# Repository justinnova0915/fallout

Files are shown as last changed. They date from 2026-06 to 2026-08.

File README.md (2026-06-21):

# TALOS-01 // Desktop Helper

The TALOS-01 is a desktop device designed to make navigating workspace-heavy, tiling operating systems (like Arch Linux Hyprland or macOS) more straightforward by making it physical. No more memorizing convoluted keyboard shortcuts just to move a window. This is my Fallout project for Hack Club, so I'm super excited to share it!

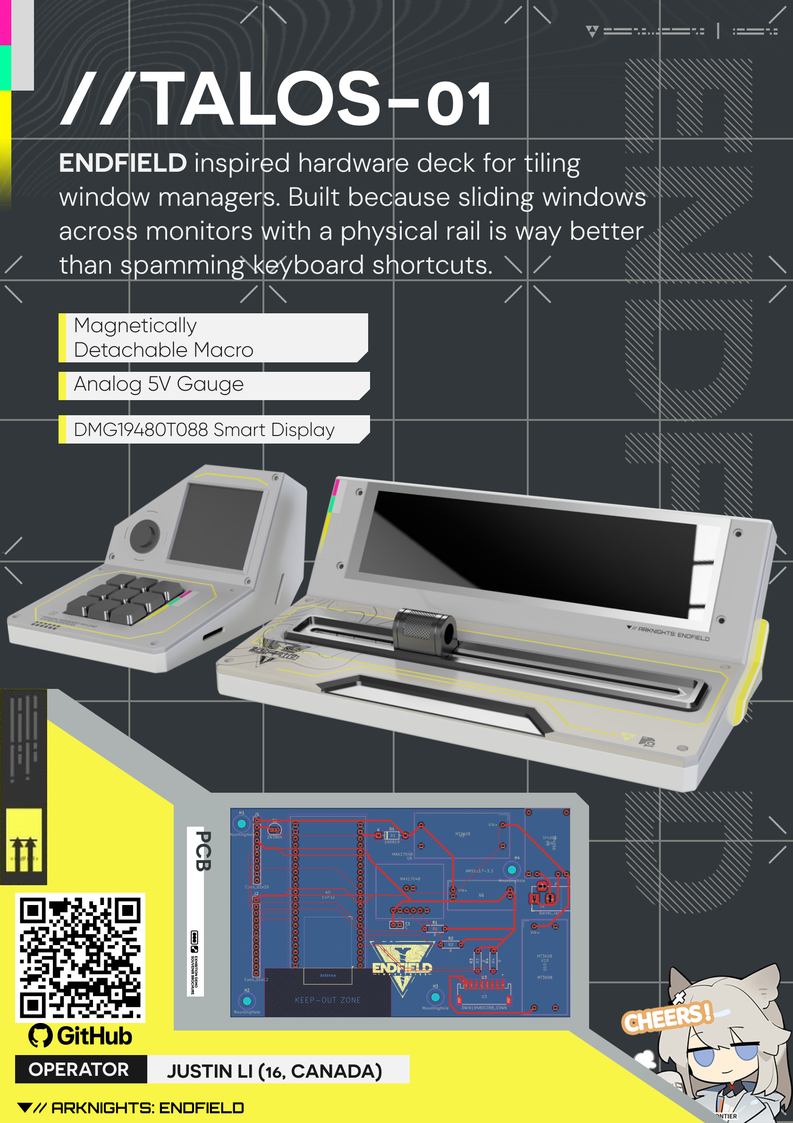
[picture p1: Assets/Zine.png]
Zine


## Why TALOS-01?

Tiling window managers like Hyprland are great, but relying entirely on abstract keybinds can get annoying and lacks physical intuition. The goal of TALOS-01 is to turn window and workspace management into a tactile experience.

## Custom Features

- The device splits into a Main Console and a Macro Pad that snap together using strong magnet pogo pins.
- The device uses an MGN7H miniature linear rail with a button on it to let you grab and slide windows across active workspaces.
- Dedicated DMG19480T088_01WN screen displays useful widgets (time, weather, Discord call status) to free up your main monitor real estate entirely for games or code.
- A custom 3x3 macro pad module for standard macro inputs.
- A physical 5V analog needle voltmeter to display real-time metrics like CPU usage or core temperatures.
- Powerful ESP32 Controller for the brain of the device. Communicates with your PC over Bluetooth.
- Supports wireless power using two internal 18650 batteries, or wired over USB-C.

## Device Design

The TALOS-01 design is heavily inspired by the design language of *Arknights: Endfield*. The entire body uses a matching color palette of black, grey, white, and yellow, detailed with topographic lines and techy text accents.
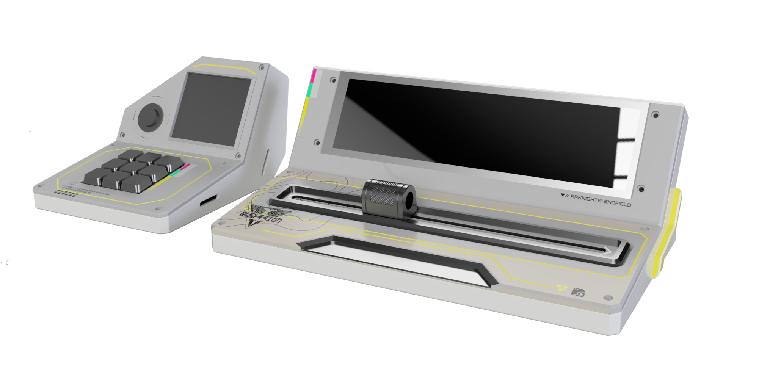
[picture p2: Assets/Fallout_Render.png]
3D Model


> Disclaimer: This project is a non-commercial, fan-made creation featuring visual and UI assets inspired by *Arknights: Endfield*, which remain the intellectual property of **Hypergryph**.

* **PCB and circuitry:**
It's built around a custom parent PCB that hosts every single chip. The board has exposed headers to connect to the moving slider handle and the macro pad (excuse any messy routing) ;).  
To power it, you can plug in USB-C to feed the TP4056 charging circuit, or let it run completely wireless off the 18650 batteries. Power leaving the circuit is stepped up using two independent MT3608 boost converters (a 12V line for the smart display and a 5V line for the ESP32 and voltmeter), before hitting an AMS1117-3.3 linear regulator for the shared sensor bus.
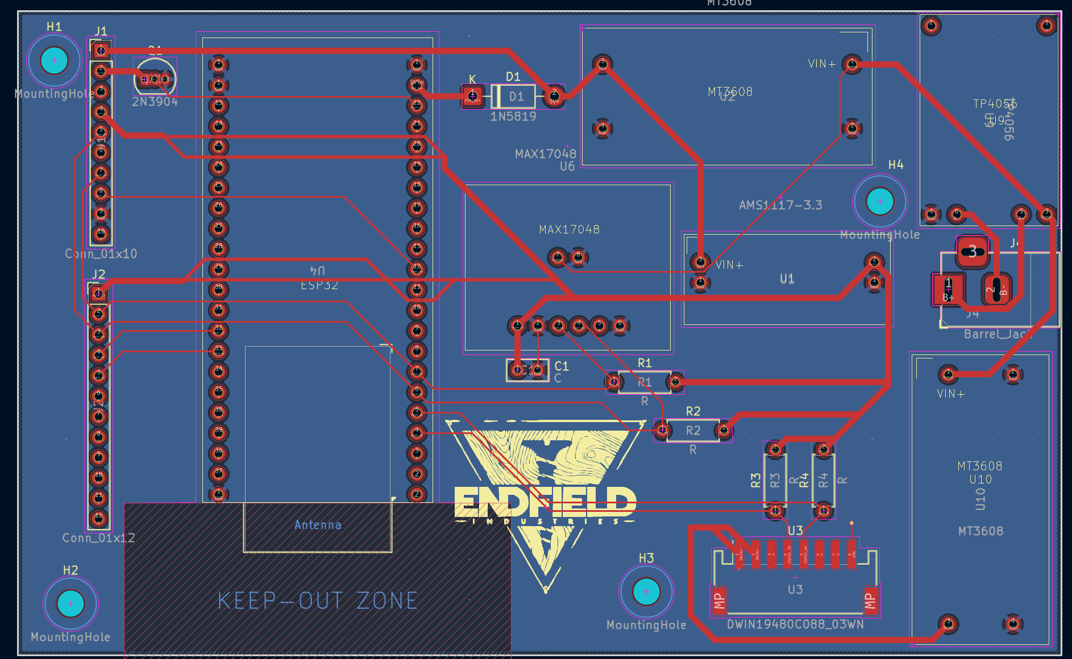
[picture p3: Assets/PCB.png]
PCB


* **The Slider & Encoder:** The custom 3D-printed handle rides on the MGN7H rail and holds a DRV2605 driver with a motor to deliver physical haptic feedback clicks as you pass items. Distance tracking is calculated using two SS49E hall effect sensors positioned exactly a quarter turn from each other on the bottom of the block. All sensors and drivers tucked inside the moving handle connect back to the parent PCB via a Flat Flexible Cable (FFC).

* **Macro Pad:** To avoid a massive, fragile bundle of wires across the split-enclosure gap, I put a PCF8574 IO expander to condense the 3x3 matrix, gauge, and power button down into a simple 4-line I2C bus, meaning the whole wing connection only needs 7 physical pogo pins to bridge the gap! The analog needle gauge runs on a 5V scale, but the ESP32 can only natively supply a 3.3V logic signal. I put together a simple 2N3094 transistor circuit to shift the downstream signal up cleanly to the required 5V.

## Firmware and Software
The screen graphics are built and flashed to the hardware independently using DWIN's native configuration environment and software utility tools. This allows the smart display to handle its own graphics processing over an 8-pin connection to the ESP32. This stops the ESP32 from lagging out under heavy rendering, so it can focus purely on passing lightweight UI control commands over UART!

On the desktop side, a custom-written daemon in GOLANG runs continuously to translate signals coming from the ESP32 over Bluetooth and send information to the device.

## How to Build and Use

#### 1. Hardware Assembly
1. **PCB:** Get the board fabricated using the gerbers files inside `Fallout_PCB`.
2. **Components:** Grab all components listed in the [BOM](https://github.com/justinnova0915/fallout/blob/main/BOM.csv).
3. **3D Printing & Assembly:** Print the housing from `Fallout_CAD`, and assemble according to the 3d model.
4. **Wiring Diagram**  
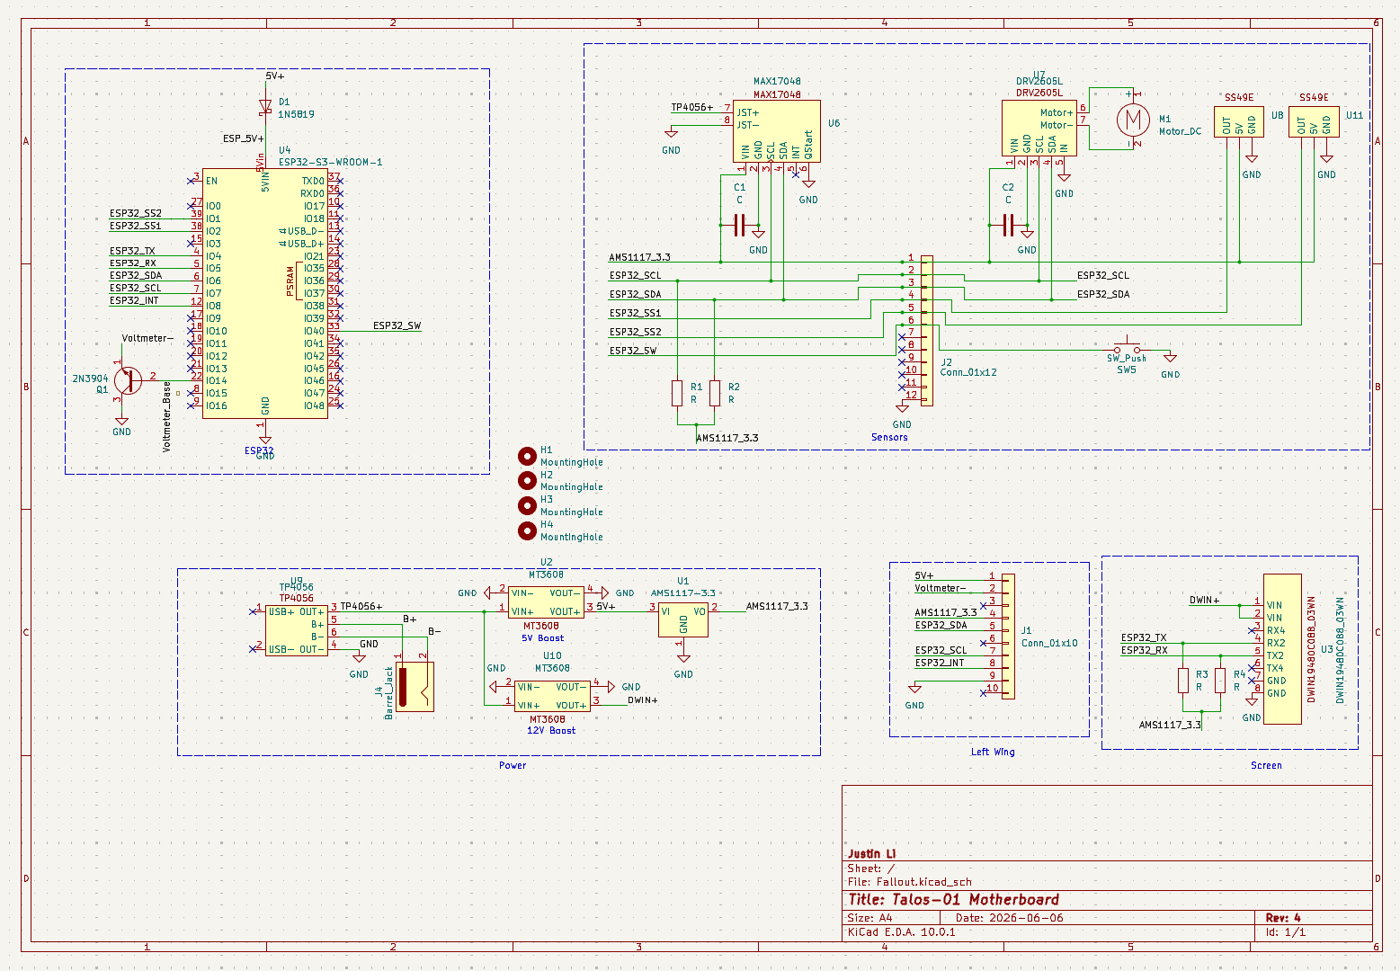
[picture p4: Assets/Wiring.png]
Wiring Diagram
  
Wiring diagram for the main board  
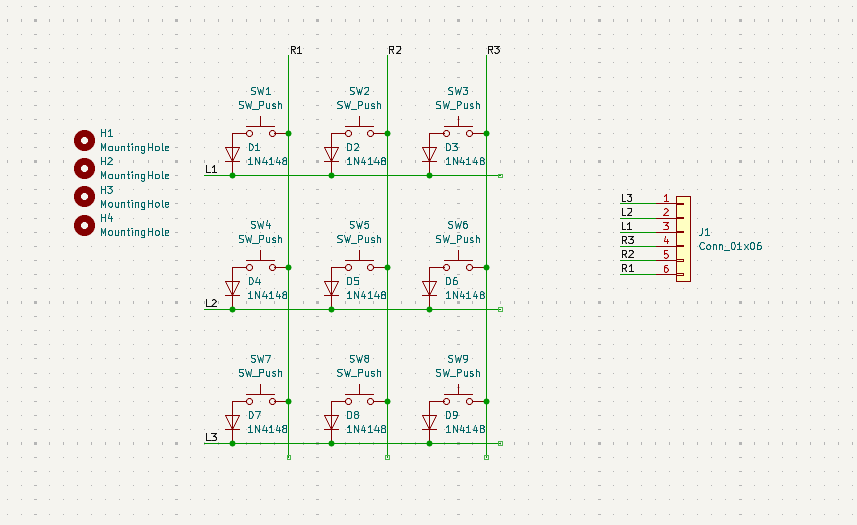
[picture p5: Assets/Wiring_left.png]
Macro Pad Wiring Diagram
  
Macro Pad Wiring Diagram
#### 2. Flashing Firmware
- **Smart Display:** The screen graphics are built and flashed to the hardware independently using DWIN's native configuration environment and software utility tools call DGUS. Simply follow their Bilibili tutorial.
- **ESP32 Core:** Open the `Fallout_Software/Firmware` project in your environment, then build and flash using vscode's esp-idf tool.

#### 3. Desktop Software Setup
The desktop side uses a custom daemon written in `GO` that runs continuously to catch Bluetooth strings from the ESP32 and talk to your window manager.
1. Move into the daemon directory:
    ```bash
    cd Fallout_Software/Daemon
    ```
2. Build the binary:
    ```bash
    go build main.go
    ```
3. Boot it on startup by adding it to your `hyprland.conf`:
    ```ini
    exec-once = /path/to/talos-daemon
    ```

## Resources

#### BOM
I got most of my components in person in China, but I have found equivalents for around the same price on Taobao, so that is what my BOM is going to be based off of.

You can get the BOM [here](https://github.com/justinnova0915/fallout/blob/main/BOM.xlsx).

#### CAD
The CAD files are under [`Fallout_CAD`](https://github.com/justinnova0915/fallout/tree/main/Fallout_CAD). I designed it in Fusion so you can find the f3d and stp files there.

#### PCB
> Since I was using the breakout or module versions of most ICs (it's my first PCB!), I had to make custom symbol and footprints for them.

The KiCAD source files are under [`Fallout_PCB`](https://github.com/justinnova0915/fallout/tree/main/Fallout_PCB)

#### Code
The ESP32 code is written in `C++` using `ESP-IDF`, and the Hyprland Daemon is written in `GO`.

The Code is under [`Fallout_Software`](https://github.com/justinnova0915/fallout/tree/main/Fallout_Software)

## Credits

Thanks so much to the folks on Discord and Reddit for reviewing and helping me refine the electronics! Thanks also to Hack Club for running the Fallout event which sponsored this hardware build!

## License

This project is licensed under `GNU GPLv3`.

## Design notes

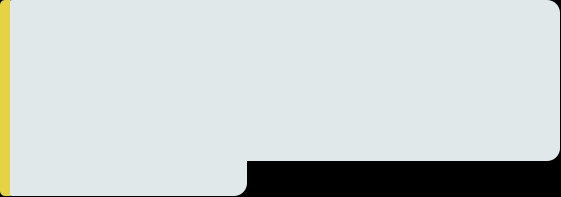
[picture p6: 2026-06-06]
Fallout_UI/Assets/bg/01Time_Background.png

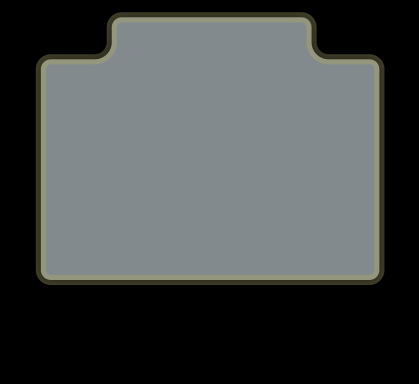
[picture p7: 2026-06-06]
Fallout_UI/Assets/bg/Workspace_background_transition/03WorkspaceBackground.png

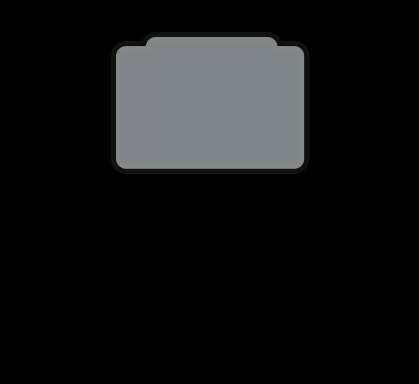
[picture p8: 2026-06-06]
Fallout_UI/Assets/bg/Workspace_background_transition/01WorkspaceBackground.png

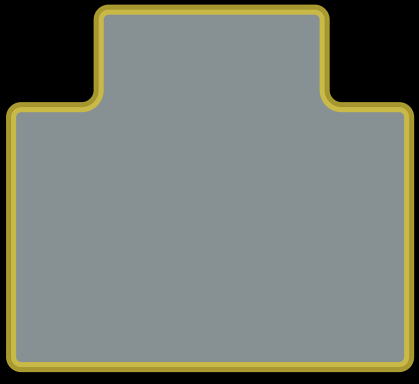
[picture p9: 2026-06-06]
Fallout_UI/Assets/bg/Workspace_background_transition/06WorkspaceBackground.png

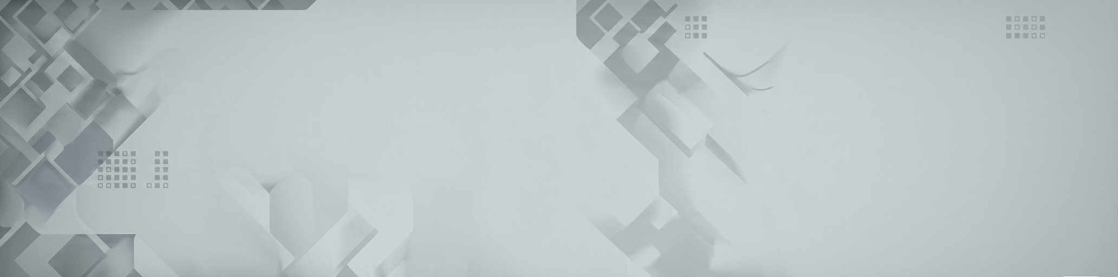
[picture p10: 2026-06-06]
Fallout_UI/Assets/01Background.png.png

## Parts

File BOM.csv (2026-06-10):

Talos-01 BOM - English Ver. |  |  | Convertion Rate
 |  | CNY/USD | 0.15
Product Name | Shop Name | Product Link | Model/Style | Quantity | Price | Shipping | Total Paid
Magnetic connector headphone charging test pogo pin male/female seat bending magnetic contact connector | Magnetic Connector Factory | https://item.taobao.com/item.htm?id=967973228845 | 6PIN magnetic male and female seat with ears | 2 | $0.72 | $0.74 | $2.18
DC voltmeter 85C1-V pointer type panel meter small mechanical voltmeter 1~3KV maintenance voltage | Shanghai Kailan Electronics Appliance City | https://item.taobao.com/item.htm?id=44135586571 | DC 5V [small backpack installation] | 1 | $1.52 | $- | $1.52
2A boost board MT3608 DC-DC boost module wide voltage input 2/24V to 5/9/12/28V adjustable | Jiexingtai Electronics | https://item.taobao.com/item.htm?id=750521428831 | 2A boost board ordinary version | 1 | $0.16 | $0.40 | $0.55
Dual row female 2.54mm single row female pin header socket pin socket 2.0 1/2/3/4/6/10-40P | risym Flagship Store | https://item.taobao.com/item.htm?id=13321689910 | 1x40p 2.54MM straight plug single row female black 10 pcs | 1 | $0.44 | $- | $0.44
Single row pin dual row pin copper pitch 2.54MM 1*2/3/4/5/6/7/8/10/12/20/30P gold-plated pin header | risym Flagship Store | https://item.taobao.com/item.htm?id=593411651824 | 1*40P copper pin header single row pin 2.54MM 10 pcs | 1 | $0.51 | $- | $0.51
Metal button switch self-locking self-resetting waterproof small round LED with power light car 12/16/19/22mm | Batu Electrical | https://item.taobao.com/item.htm?id=787575307428 | Ring yellow light flat button; 12mm; 3-6V; self-resetting (without wire) | 1 | $0.30 | $- | $0.30
AMS1117 power module 1.2V 1.5V 1.8V 2.5V 3.3V 5.0V voltage regulator buck module | Jiexingtai Electronics | https://item.taobao.com/item.htm?id=760134372596 | 3.3V | 1 | $0.06 | $0.55 | $0.79
2A boost board MT3608 DC-DC boost module wide voltage input 2/24V to 5/9/12/28V adjustable |  | https://item.taobao.com/item.htm?id=750521428831 | 2A boost board ordinary version | 1 | $0.16 | $- | $-
TP4056 1A lithium battery charging board Type-C charging module USB interface charging protection 2-in-1 |  | https://item.taobao.com/item.htm?id=737840642554 | TYPE-C interface | 1 | $0.03 | $- | $-
HAKKO soldering iron FX-888D constant temperature welding station set combo hako 936 upgrade version | Dongguan Rongbute Electronics | https://item.taobao.com/item.htm?id=771567441346 | None | 1 | $32.47 | $- | $32.47
Deer Fairy ceramic tweezers stainless steel jump wire phone repair curved anti-static high temperature resistant precision pointed clip | Deer Fairy Flagship Store | https://item.taobao.com/item.htm?id=877710167002 | Stainless steel [curved head 15°] replaceable head ceramic tweezers | 1 | $1.54 | $- | $16.29
[Discount Price] Deer Fairy powerful desoldering pump large suction solder sucker desoldering gun soldering iron solder suction gun artifact large welding gun |  | https://item.taobao.com/item.htm?id=885201544620 | Blue (single ring anti-slip) desoldering pump + 2 high-temperature hoses | 1 | $1.34 | $- | $-
Deer Fairy desoldering wick desoldering wire welding phone repair motherboard powerful tool solder remover wick solder removal strip |  | https://item.taobao.com/item.htm?id=670202327708 | Desoldering wick 3030 [width 3.0mm, length 3 meters] | 1 | $1.61 | $- | $-
Deer Fairy multifunctional soldering station welding workbench PCB motherboard repair clip bracket circuit board fixing fixture |  | https://item.taobao.com/item.htm?id=648692766840 | [Upgraded Version] Magnifier + 2 PCB clips + 4 magnetic pillars | 1 | $11.79 | $- | $-
YORK951 flux pen clean-free eco-friendly flux pen contains flux rosin welding water pen KESTER-951 | Deloda | https://item.taobao.com/item.htm?id=21085979118 | 951 flux pen (including flux) 1 pc | 1 | $0.74 | $0.74 | $1.48
Japan Hirosaki solder wire hollow core with rosin 0.3 0.8mm low temperature 63A household soldering iron solder wire 1.0 | Japan Hirosaki Solder Wire | https://item.taobao.com/item.htm?id=614104575953 | New formula Hirosaki 100g 0.8mm | 1 | $6.64 | $- | $6.64
8PIN 2.0 interface set | Beijing DWIN Technology Co., Ltd. | https://item.taobao.com/item.htm?id=679117523470 | 8PIN 2.0 interface kit (SD003) | 1 | $3.76 | $2.36 | $6.13
Germany miniature linear guide rail slider linear rail MGN9H MGW12H 12C 9C 7C 15C 7H 15H 5C | muh Flagship Store | https://item.taobao.com/item.htm?id=709992228016 | MGN7H extended block | 2 | $2.95 | $- | $14.75
Germany miniature linear guide rail slider linear rail MGN9H MGW12H 12C 9C 7C 15C 7H 15H 5C |  | https://item.taobao.com/item.htm?id=709992228016 | MGN7 guide rail = 100MM = 10 cm | 5 | $1.77 | $- | $-
[Discount Price] Tu Ba hot melt nut injection molded copper nut insert M1 M2 M3 M4 M5 M6 M8 knurled copper brass nut insert copper flower nut | Jinchao Official Flagship Store | https://item.taobao.com/item.htm?id=899448134936 | M3*10*4.2 (20 pcs) | 1 | $0.57 | $- | $10.18
[Discount Price] Tu Ba hot melt nut injection molded copper nut insert M1 M2 M3 M4 M5 M6 M8 knurled copper brass nut insert copper flower nut |  | https://item.taobao.com/item.htm?id=899448134936 | M3*8*4.2 (50 pcs) | 1 | $1.05 | $- | $-
[Discount Price] Tu Ba hot melt nut injection molded copper nut insert M1 M2 M3 M4 M5 M6 M8 knurled copper brass nut insert copper flower nut |  | https://item.taobao.com/item.htm?id=899448134936 | M3*6*4.2 (50 pcs) | 1 | $0.78 | $- | $-
[Discount Price] Tu Ba hot melt nut injection molded copper nut insert M1 M2 M3 M4 M5 M6 M8 knurled copper brass nut insert copper flower nut |  | https://item.taobao.com/item.htm?id=899448134936 | M3*4*4.2 (50 pcs) | 1 | $0.58 | $- | $-
[Discount Price] Tu Ba hot melt nut injection molded copper nut insert M1 M2 M3 M4 M5 M6 M8 knurled copper brass nut insert copper flower nut |  | https://item.taobao.com/item.htm?id=899448134936 | M2*10*3.2 (20 pcs) | 1 | $0.53 | $- | $-
[Discount Price] Tu Ba hot melt nut injection molded copper nut insert M1 M2 M3 M4 M5 M6 M8 knurled copper brass nut insert copper flower nut |  | https://item.taobao.com/item.htm?id=899448134936 | M2*8*3.2 (50 pcs) | 1 | $0.89 | $- | $-
[Discount Price] Tu Ba hot melt nut injection molded copper nut insert M1 M2 M3 M4 M5 M6 M8 knurled copper brass nut insert copper flower nut |  | https://item.taobao.com/item.htm?id=899448134936 | M2*6*3.2 (50 pcs) | 1 | $0.77 | $- | $-
[Discount Price] Tu Ba hot melt nut injection molded copper nut insert M1 M2 M3 M4 M5 M6 M8 knurled copper brass nut insert copper flower nut |  | https://item.taobao.com/item.htm?id=899448134936 | M2*4*3.2 (50 pcs) | 1 | $0.52 | $- | $-
[Discount Price] Black 304 stainless steel thin head hex socket screw DIN7984 low head extended bolt M3 M4 M5 M6-M12 |  | https://item.taobao.com/item.htm?id=919963730201 | M3*10 (50 pcs) black | 1 | $0.64 | $- | $-
[Discount Price] Black 304 stainless steel thin head hex socket screw DIN7984 low head extended bolt M3 M4 M5 M6-M12 |  | https://item.taobao.com/item.htm?id=919963730201 | M3*8 (50 pcs) black | 1 | $0.57 | $- | $-
[Discount Price] Black 304 stainless steel thin head hex socket screw DIN7984 low head extended bolt M3 M4 M5 M6-M12 |  | https://item.taobao.com/item.htm?id=919963730201 | M3*6 (50 pcs) black | 1 | $0.52 | $- | $-
[Discount Price] Black 304 stainless steel thin head hex socket screw DIN7984 low head extended bolt M3 M4 M5 M6-M12 |  | https://item.taobao.com/item.htm?id=919963730201 | M3*4 (50 pcs) black | 1 | $0.47 | $- | $-
[Discount Price] Black 304 stainless steel thin head hex socket screw DIN7984 low head extended bolt M3 M4 M5 M6-M12 |  | https://item.taobao.com/item.htm?id=919963730201 | M2*10 (50 pcs) black | 1 | $0.45 | $- | $-
[Discount Price] Black 304 stainless steel thin head hex socket screw DIN7984 low head extended bolt M3 M4 M5 M6-M12 |  | https://item.taobao.com/item.htm?id=919963730201 | M2*8 (50 pcs) black | 1 | $0.42 | $- | $-
[Discount Price] Black 304 stainless steel thin head hex socket screw DIN7984 low head extended bolt M3 M4 M5 M6-M12 |  | https://item.taobao.com/item.htm?id=919963730201 | M2*6 (100 pcs) black | 1 | $0.76 | $- | $-
[Discount Price] Black 304 stainless steel thin head hex socket screw DIN7984 low head extended bolt M3 M4 M5 M6-M12 |  | https://item.taobao.com/item.htm?id=919963730201 | M2*4 (100 pcs) black | 1 | $0.68 | $- | $-
Suning 18650 lithium battery charger large capacity 3.7V strong light flashlight small fan 4.2V headlamp 1956 | Suning.com Official Flagship Store | https://item.taobao.com/item.htm?id=680631931401 | 2 pcs 12950mWh flat head + 1 free pc of the same model | 1 | $8.84 | $- | $8.84
IP5328P power bank bidirectional fast charging module mobile power supply motherboard 3.7V to 5V 9V 12V boost | Jiexingtai Electronics | https://item.taobao.com/item.htm?id=762091560429 | None | 1 | $1.62 | $0.55 | $6.67
ESP32 S3 core board onboard 1-N16R8 N8R2 N8R8 S3-DevKitC-1 module development board |  | https://item.taobao.com/item.htm?id=915770459444 | With antenna ESP32-S3 N16R8 (soldered) | 1 | $3.25 | $- | $-
MT6701 magnetic encoder magnetic induction angle measurement sensor module 14bit high precision replacement for AS5600 |  | https://item.taobao.com/item.htm?id=975995430628 | Soldered pin header | 1 | $1.25 | $- | $-
Outemu dustproof mechanical keyboard switch body blue red brown black purple green silver silent white gray switch tester accessories | Xinyang Peripherals | https://item.taobao.com/item.htm?id=626986550029 | Standard brown switch 10 pcs | 1 | $0.59 | $- | $0.59
MAX17048 fuel gauge and battery monitor STEMMA JST PH & QT/Qwiic | Mairui Electronic Module Manufacturer | https://item.taobao.com/item.htm?id=951093914740 | None | 1 | $5.09 | $0.74 | $5.83
Phone bracelet vibrator motor 0827/1027/30/34 flat SMD coreless motor with wire motor | Tejiate Digital Specialty Store | https://item.taobao.com/item.htm?id=577868295040 | 0827 motor outer diameter 8MM thickness 2.7MM | 1 | $0.27 | $- | $0.27
DRV2605L Haptic Motor Controller motor driver module | diymore Flagship Store | https://item.taobao.com/item.htm?id=625769283873 | None | 1 | $2.41 | $- | $2.41
Multi-pole magnetic scale universal magnetic strip linear displacement sensor magnetic pitch 1/2/5mm optional | Jingrui New Materials | https://item.taobao.com/item.htm?id=959214645549 | Rubber magnet + stainless steel carrier strip; 2mm (1 meter version) | 1 | $11.81 | $0.44 | $12.25
[Discount Price] 3M double-sided tape strong adhesive sponge tape car automotive VHB waterproof traceless high viscosity fixed wall | 3M Haotie Franchise Store | https://item.taobao.com/item.htm?id=592230232424 | 1cm wide * 3m long [Upgraded Version] | 1 | $1.07 | $- | $1.07
3J double-conductive copper foil tape pure copper double-sided conductive copper foil tape conductive tape shielding tape single-sided tape | 3J Flagship Store | https://item.taobao.com/item.htm?id=19345387931 | 0.05 thickness * 50mm width * 20 meters | 1 | $5.17 | $- | $5.17
8.88 inch DWIN smart serial screen DMG19480C088_03W music playback touch WIFI optional | Beijing DWIN Technology Co., Ltd. | https://item.taobao.com/item.htm?id=612878714371 | DMG19480C088_03WN | 1 | $40.59 | $2.36 | $42.95
Ultra-narrow ultra-fine soft silicone light strip 24V line linear light embedded light slot linear 12V low voltage waterproof light bar | Little Elephant Lighting | https://item.taobao.com/item.htm?id=744195758598 | 12V low voltage silicone (width 4MM * thickness 8MM) 1 meter price; yellow | 1 | $0.93 | $- | $0.93
Magnetic connector headphone charging test pogo pin male/female seat bending magnetic contact connector | Magnetic Connector Factory | https://item.taobao.com/item.htm?id=967973228845 | 4PIN magnetic male and female seat with ears | 1 | $0.61 | $0.74 | $1.34
High head metal button switch self-locking self-resetting round inching with light power button 12/16/19/22mm | Maifeng Electrical | https://item.taobao.com/item.htm?id=775942345988 | High head ring power red light; 22mm; 3-6V; self-resetting (without wire) | 1 | $0.94 | $- | $0.94
Ultra-soft silicone wire high temperature resistant aero-modeling new energy tinned copper flexible wire 16 18 20 22 24 28 30AWG | Benmu Flagship Store | https://item.taobao.com/item.htm?id=694610952234 | 30AWG orange / 5 meters | 1 | $0.56 | $- | $3.24
Ultra-soft silicone wire high temperature resistant aero-modeling new energy tinned copper flexible wire 16 18 20 22 24 28 30AWG |  | https://item.taobao.com/item.htm?id=694610952234 | 30AWG brown / 5 meters | 1 | $0.56 | $- | $-
Ultra-soft silicone wire high temperature resistant aero-modeling new energy tinned copper flexible wire 16 18 20 22 24 28 30AWG |  | https://item.taobao.com/item.htm?id=694610952234 | 30AWG purple / 5 meters | 1 | $0.42 | $- | $-
Ultra-soft silicone wire high temperature resistant aero-modeling new energy tinned copper flexible wire 16 18 20 22 24 28 30AWG |  | https://item.taobao.com/item.htm?id=694610952234 | 30AWG green / 5 meters | 1 | $0.56 | $- | $-
Ultra-soft silicone wire high temperature resistant aero-modeling new energy tinned copper flexible wire 16 18 20 22 24 28 30AWG |  | https://item.taobao.com/item.htm?id=694610952234 | 30AWG red / 5 meters | 1 | $0.56 | $- | $-
Ultra-soft silicone wire high temperature resistant aero-modeling new energy tinned copper flexible wire 16 18 20 22 24 28 30AWG |  | https://item.taobao.com/item.htm?id=694610952234 | 30AWG black / 5 meters | 1 | $0.56 | $- | $-
FPC/FFC adapter board soldered 0.5mm/1.0mm pitch connector to DIP 2.54 flexible ribbon cable adapter socket | Jieyisi Technology | https://item.taobao.com/item.htm?id=746618533227 | 12P; 0.5mm; soldered FPC seat + straight pin | 2 | $0.41 | $- | $1.65
FPC/FFC adapter board soldered 0.5mm/1.0mm pitch connector to DIP 2.54 flexible ribbon cable adapter socket |  | https://item.taobao.com/item.htm?id=746618533227 | 12P; 0.5mm; soldered FPC seat + curved pin | 2 | $0.41 | $- | $-
[Discount Price] 5 pieces FFC/FPC flexible ribbon cable flat connecting line 1.0/0.5mm same direction/reverse direction 10/16/20/24-40P | zave Flagship Store | https://item.taobao.com/item.htm?id=626935294271 | 12P same direction 0.5mm pitch length 300mm (5 pcs) | 1 | $0.40 | $- | $1.16
[Discount Price] PCF8574 module microcontroller I/O expansion board module PCF8574T module I2C interface |  | https://item.taobao.com/item.htm?id=715839930914 | PCF8574 module blue board | 1 | $0.76 | $- | $-
Talos-01 BOM - Original Chinese Ver. |  |  |  |  |  |  | $189.54
商品名称 | 店铺名称 | 商品链接 | 型号款式 | 商品数量 | 商品金额 | 运费 | 实付金额
磁吸连接器耳机充电测试弹簧针pogopin公母座折弯磁吸触点连接器 | 磁吸连接器工厂 | https://item.taobao.com/item.htm?id=967973228845 | 6PIN磁吸公母座带耳 | 2 | ¥4.90 | ¥5.00 | ¥14.80
直流电压表85C1-V指针式表头安装式小型机械伏特表1~3KV维修电压 | 上海凯蓝电子电器城 | https://item.taobao.com/item.htm?id=44135586571 | 直流5V[小背包安装] | 1 | ¥10.30 | ¥- | ¥10.30
2A升压板 MT3608 DC-DC升压模块 宽压输入2/24V升5/9/12/28V可调 | 捷兴泰电子 | https://item.taobao.com/item.htm?id=750521428831 | 2A升压板 普通版 | 1 | ¥1.06 | ¥2.70 | ¥3.76
双排母2.54mm单排母排针母座排座针插座插针2.0 1/2/3/4/6/10-40P | risym旗舰店 | https://item.taobao.com/item.htm?id=13321689910 | 1x40p 2.54MM直插单排母黑色 10个 | 1 | ¥2.95 | ¥- | ¥2.95
单排针双排针铜间距2.54MM1*2/3/4/5/6/7/8/10/12/20/30P镀金插针 | risym旗舰店 | https://item.taobao.com/item.htm?id=593411651824 | 1*40P铜排针 单排针2.54MM 10条 | 1 | ¥3.45 | ¥- | ¥3.45
金属按钮开关自锁自复位防水小型圆形led带电源灯车12/16/19/22mm | 八图电气 | https://item.taobao.com/item.htm?id=787575307428 | 环形黄灯平钮;12mm;3-6V;自复位（不带线） | 1 | ¥2.05 | ¥- | ¥2.05
AMS1117电源模块 1.2V 1.5V 1.8V 2.5V 3.3V 5.0V 稳压降压模块 | 捷兴泰电子 | https://item.taobao.com/item.htm?id=760134372596 | 3.3V | 1 | ¥0.40 | ¥3.70 | ¥5.38
2A升压板 MT3608 DC-DC升压模块 宽压输入2/24V升5/9/12/28V可调 |  | https://item.taobao.com/item.htm?id=750521428831 | 2A升压板 普通版 | 1 | ¥1.06
TP4056 1A锂电池充电板Type-C充电模块USB接口充电保护二合一 |  | https://item.taobao.com/item.htm?id=737840642554 | TYPE-C接口 | 1 | ¥0.22
HAKKO白光电烙铁FX-888D恒温电焊台套装组合 hako 936升级版 | 东莞市荣步特电子 | https://item.taobao.com/item.htm?id=771567441346 | 暂无 | 1 | ¥220.00 | ¥- | ¥220.00
鹿仙子陶瓷镊子不锈钢飞线手机维修弯头防静电耐高温精密尖头夹子 | 鹿仙子旗舰店 | https://item.taobao.com/item.htm?id=877710167002 | 不锈钢【弯头15°】可换头陶瓷镊子 | 1 | ¥10.44 | ¥- | ¥110.34
【优惠价】鹿仙子强力吸锡器大吸力吸焊器吸锡枪电烙铁焊锡吸枪神器大号焊枪 |  | https://item.taobao.com/item.htm?id=885201544620 | 蓝(单环防滑)吸锡器+2根高温软管 | 1 | ¥9.09
鹿仙子吸锡带吸锡线焊接手机维修主板强力工具吸锡器除焊带去锡条 |  | https://item.taobao.com/item.htm?id=670202327708 | 吸锡线3030【宽3.0mm 长3米】 | 1 | ¥10.91
鹿仙子多功能焊台焊接工作台pcb主板维修夹子支架电路板固定夹具 |  | https://item.taobao.com/item.htm?id=648692766840 | 【升级款】放大镜+2个PCB夹+4个磁柱 | 1 | ¥79.90
YORK951助焊笔免清洗环保助焊笔含助焊剂松香焊接水笔KESTER-951 | 德乐达deloda | https://item.taobao.com/item.htm?id=21085979118 | 951助焊笔 （含助焊剂）1支 | 1 | ¥5.00 | ¥5.00 | ¥10.00
日本广崎焊锡丝空芯带松香0.3 0.8mm低温63A家用电烙铁焊丝1.0 | 日本广崎HIROSAKI锡丝 | https://item.taobao.com/item.htm?id=614104575953 | 新配方 广崎 100g 0.8mm | 1 | ¥45.00 | ¥- | ¥45.00
8PIN2.0接口套装 | 北京迪文科技有限公司 | https://item.taobao.com/item.htm?id=679117523470 | 8PIN2.0接口套件（SD003） | 1 | ¥25.50 | ¥16.00 | ¥41.50
德国微型直线导轨滑块线轨MGN9H MGW12H 12C 9C 7C 15C 7H 15H 5C | muh旗舰店 | https://item.taobao.com/item.htm?id=709992228016 | MGN7H 加长块 | 2 | ¥19.97 | ¥- | ¥99.94
德国微型直线导轨滑块线轨MGN9H MGW12H 12C 9C 7C 15C 7H 15H 5C |  | https://item.taobao.com/item.htm?id=709992228016 | MGN7导轨=100MM=10厘米 | 5 | ¥12.00
【优惠价】土八热熔螺母注塑铜螺母镶件M1M2M3M4M5M6M8滚花铜螺帽嵌件铜花母 | 金超官方旗舰店 | https://item.taobao.com/item.htm?id=899448134936 | M3*10*4.2(20个) | 1 | ¥3.83 | ¥- | ¥68.96
【优惠价】土八热熔螺母注塑铜螺母镶件M1M2M3M4M5M6M8滚花铜螺帽嵌件铜花母 |  | https://item.taobao.com/item.htm?id=899448134936 | M3*8*4.2(50个) | 1 | ¥7.08
【优惠价】土八热熔螺母注塑铜螺母镶件M1M2M3M4M5M6M8滚花铜螺帽嵌件铜花母 |  | https://item.taobao.com/item.htm?id=899448134936 | M3*6*4.2(50个) | 1 | ¥5.29
【优惠价】土八热熔螺母注塑铜螺母镶件M1M2M3M4M5M6M8滚花铜螺帽嵌件铜花母 |  | https://item.taobao.com/item.htm?id=899448134936 | M3*4*4.2(50个) | 1 | ¥3.90
【优惠价】土八热熔螺母注塑铜螺母镶件M1M2M3M4M5M6M8滚花铜螺帽嵌件铜花母 |  | https://item.taobao.com/item.htm?id=899448134936 | M2*10*3.2(20个) | 1 | ¥3.61
【优惠价】土八热熔螺母注塑铜螺母镶件M1M2M3M4M5M6M8滚花铜螺帽嵌件铜花母 |  | https://item.taobao.com/item.htm?id=899448134936 | M2*8*3.2(50个) | 1 | ¥6.00
【优惠价】土八热熔螺母注塑铜螺母镶件M1M2M3M4M5M6M8滚花铜螺帽嵌件铜花母 |  | https://item.taobao.com/item.htm?id=899448134936 | M2*6*3.2(50个) | 1 | ¥5.20
【优惠价】土八热熔螺母注塑铜螺母镶件M1M2M3M4M5M6M8滚花铜螺帽嵌件铜花母 |  | https://item.taobao.com/item.htm?id=899448134936 | M2*4*3.2(50个) | 1 | ¥3.50
【优惠价】黑色304不锈钢薄头内六角螺丝钉DIN7984矮头加长螺栓M3M4M5M6-M12 |  | https://item.taobao.com/item.htm?id=919963730201 | M3*10(50个)黑色 | 1 | ¥4.33
【优惠价】黑色304不锈钢薄头内六角螺丝钉DIN7984矮头加长螺栓M3M4M5M6-M12 |  | https://item.taobao.com/item.htm?id=919963730201 | M3*8(50个)黑色 | 1 | ¥3.84
【优惠价】黑色304不锈钢薄头内六角螺丝钉DIN7984矮头加长螺栓M3M4M5M6-M12 |  | https://item.taobao.com/item.htm?id=919963730201 | M3*6(50个)黑色 | 1 | ¥3.54
【优惠价】黑色304不锈钢薄头内六角螺丝钉DIN7984矮头加长螺栓M3M4M5M6-M12 |  | https://item.taobao.com/item.htm?id=919963730201 | M3*4(50个)黑色 | 1 | ¥3.20
【优惠价】黑色304不锈钢薄头内六角螺丝钉DIN7984矮头加长螺栓M3M4M5M6-M12 |  | https://item.taobao.com/item.htm?id=919963730201 | M2*10(50个)黑色 | 1 | ¥3.02
【优惠价】黑色304不锈钢薄头内六角螺丝钉DIN7984矮头加长螺栓M3M4M5M6-M12 |  | https://item.taobao.com/item.htm?id=919963730201 | M2*8(50个)黑色 | 1 | ¥2.84
【优惠价】黑色304不锈钢薄头内六角螺丝钉DIN7984矮头加长螺栓M3M4M5M6-M12 |  | https://item.taobao.com/item.htm?id=919963730201 | M2*6(100个)黑色 | 1 | ¥5.16
【优惠价】黑色304不锈钢薄头内六角螺丝钉DIN7984矮头加长螺栓M3M4M5M6-M12 |  | https://item.taobao.com/item.htm?id=919963730201 | M2*4(100个)黑色 | 1 | ¥4.62
苏宁18650锂电池充电器大容量3.7v强光手电筒小风扇4.2v头灯1956 | 苏宁易购官方旗舰店 | https://item.taobao.com/item.htm?id=680631931401 | 2节12950mWh平头送同款1节 | 1 | ¥59.90 | ¥- | ¥59.90
IP5328P 充电宝双向快充模块 移动电源主板 3.7V转5V9V12V升压 | 捷兴泰电子 | https://item.taobao.com/item.htm?id=762091560429 | 暂无 | 1 | ¥11.00 | ¥3.70 | ¥45.20
ESP32 S3核心板板载1-N16R8 N8R2 N8R8 S3-DevKitC-1模块开发板 |  | https://item.taobao.com/item.htm?id=915770459444 | 带天线ESP32-S3 N16R8（已焊接） | 1 | ¥22.00
MT6701磁编码器 磁感应角度测量传感器模块14bit高精度替代AS5600 |  | https://item.taobao.com/item.htm?id=975995430628 | 焊好排针 | 1 | ¥8.50
高特防尘机械键盘轴体青轴红轴茶黑紫绿银静音白灰换轴试轴器配件 | 芯扬外设 | https://item.taobao.com/item.htm?id=626986550029 | 标准茶轴10个 | 1 | ¥3.97 | ¥- | ¥3.97
MAX17048 电量计和电池监测器 STEMMA JST PH & QT/Qwiic | 迈瑞电子模块生产商 | https://item.taobao.com/item.htm?id=951093914740 | 暂无 | 1 | ¥34.50 | ¥5.00 | ¥39.50
手机手环振动器马达 0827/1027/30/34扁平贴片空心杯电机带线马达 | 特加特数码专营店 | https://item.taobao.com/item.htm?id=577868295040 | 0827马达 外径8MM 厚度2.7MM | 1 | ¥1.80 | ¥- | ¥1.80
DRV2605L Haptic Motor Controller马达驱动模块 | diymore旗舰店 | https://item.taobao.com/item.htm?id=625769283873 | 暂无 | 1 | ¥16.33 | ¥- | ¥16.33
多极磁栅尺 通用型磁条 直线位移传感器 磁距1/2/5mm可选 | 精锐新材料 | https://item.taobao.com/item.htm?id=959214645549 | 橡胶磁+不锈钢载条;2mm（1米款） | 1 | ¥80.00 | ¥3.00 | ¥83.00
【优惠价】3m双面胶贴强力粘胶海绵胶带汽车车用VHB防水无痕高粘度固定墙面 | 3m浩铁专卖店 | https://item.taobao.com/item.htm?id=592230232424 | 1厘米宽*3米长【升级版】 | 1 | ¥7.22 | ¥- | ¥7.22
3J双导铜箔胶带 纯铜双面导电铜箔胶带 导电胶带屏蔽胶带 单面胶 | 3j旗舰店 | https://item.taobao.com/item.htm?id=19345387931 | 0.05厚*50mm宽*20米 | 1 | ¥35.00 | ¥- | ¥35.00
8.88英寸 迪文 智能串口屏DMG19480C088_03W音乐播放触摸WIFI可选 | 北京迪文科技有限公司 | https://item.taobao.com/item.htm?id=612878714371 | DMG19480C088_03WN | 1 | ¥275.00 | ¥16.00 | ¥291.00
极窄超细软硅胶灯带24V线条线形灯嵌入式灯槽线型12V低压防水灯条 | 小象照明 | https://item.taobao.com/item.htm?id=744195758598 | 12V低压硅胶（宽4MM*厚8MM）1米价;黄色 | 1 | ¥6.30 | ¥- | ¥6.30
磁吸连接器耳机充电测试弹簧针pogopin公母座折弯磁吸触点连接器 | 磁吸连接器工厂 | https://item.taobao.com/item.htm?id=967973228845 | 4PIN磁吸公母座带耳 | 1 | ¥4.10 | ¥5.00 | ¥9.10
高头金属按钮开关自锁自复位圆形点动带灯电源按键12/16/19/22mm | 麦丰电气 | https://item.taobao.com/item.htm?id=775942345988 | 高头环形电源红灯;22mm;3-6V;自复位（不带线） | 1 | ¥6.38 | ¥- | ¥6.38
特软硅胶线耐高温航模新能源镀锡铜软线16 18 20 22 24 28 30AWG | 本木旗舰店 | https://item.taobao.com/item.htm?id=694610952234 | 30AWG橙色/5米 | 1 | ¥3.82 | ¥- | ¥21.92
特软硅胶线耐高温航模新能源镀锡铜软线16 18 20 22 24 28 30AWG |  | https://item.taobao.com/item.htm?id=694610952234 | 30AWG棕色/5米 | 1 | ¥3.82
特软硅胶线耐高温航模新能源镀锡铜软线16 18 20 22 24 28 30AWG |  | https://item.taobao.com/item.htm?id=694610952234 | 30AWG紫色/5米 | 1 | ¥2.82
特软硅胶线耐高温航模新能源镀锡铜软线16 18 20 22 24 28 30AWG |  | https://item.taobao.com/item.htm?id=694610952234 | 30AWG绿色/5米 | 1 | ¥3.82
特软硅胶线耐高温航模新能源镀锡铜软线16 18 20 22 24 28 30AWG |  | https://item.taobao.com/item.htm?id=694610952234 | 30AWG红色/5米 | 1 | ¥3.82
特软硅胶线耐高温航模新能源镀锡铜软线16 18 20 22 24 28 30AWG |  | https://item.taobao.com/item.htm?id=694610952234 | 30AWG黑色/5米 | 1 | ¥3.82
FPC/FFC转接板焊好0.5mm/1.0mm间距连接器转直插2.54软排线转接座 | 杰易斯科技 | https://item.taobao.com/item.htm?id=746618533227 | 12P;0·5mm;焊接FPC座+直针 | 2 | ¥2.80 | ¥- | ¥11.20
FPC/FFC转接板焊好0.5mm/1.0mm间距连接器转直插2.54软排线转接座 |  | https://item.taobao.com/item.htm?id=746618533227 | 12P;0·5mm;焊接FPC座+弯针 | 2 | ¥2.80
【优惠价】5条 FFC/FPC软排线扁平连接线1.0/0.5mm同向/反向10/16/20/24-40P | zave旗舰店 | https://item.taobao.com/item.htm?id=626935294271 | 12P同向 0.5mm间距 长300mm (5条) | 1 | ¥2.72 | ¥- | ¥7.89
【优惠价】PCF8574模块 单片机I/O扩展板模块 PCF8574T模块 I2C接口 |  | https://item.taobao.com/item.htm?id=715839930914 | PCF8574模块蓝板 | 1 | ¥5.17
 |  |  |  |  |  |  | ¥1,284.14

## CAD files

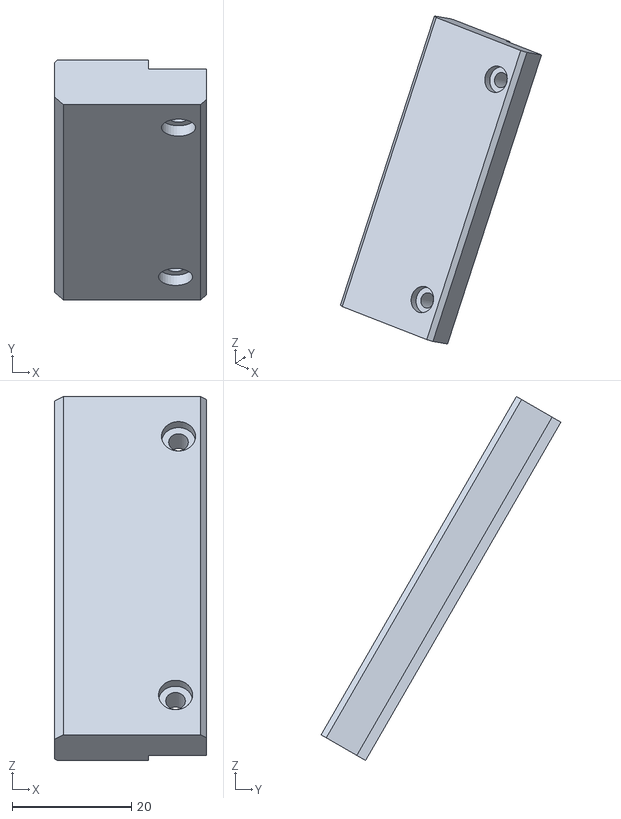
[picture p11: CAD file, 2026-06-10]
Fallout_CAD/3D_Print/Screen Cover Left.stl
25.5 x 40.1 x 60.9

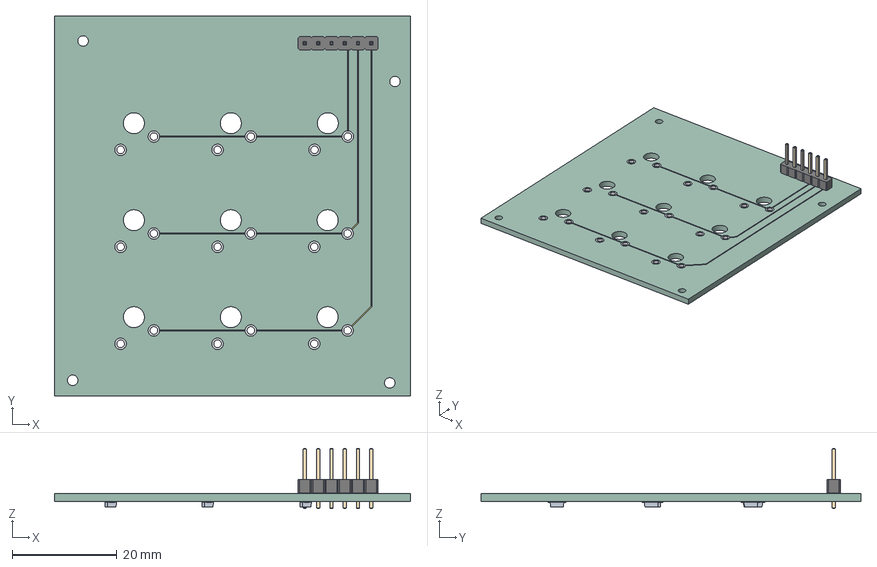
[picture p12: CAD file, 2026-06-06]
Fallout_PCB/Left_Wing/macro.step
68.0 x 72.5 x 11.5 mm
PinHeader_1x06_P2.54mm_Vertical
macro 1.2.1 x 9
Left_Wing_copper
Left_Wing_pad
Left_Wing_PCB

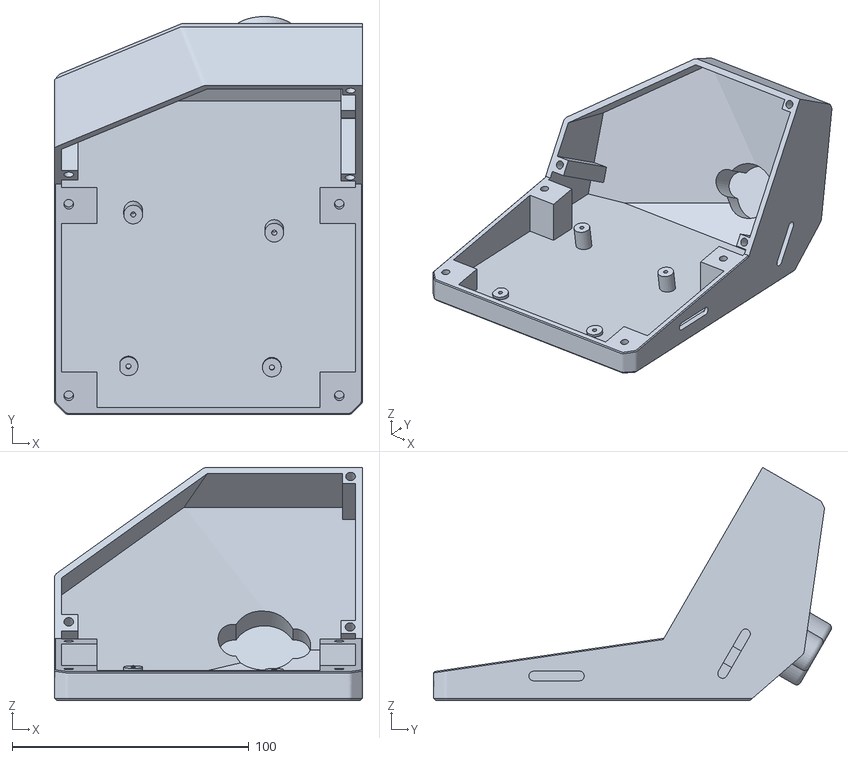
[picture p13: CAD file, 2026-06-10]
Fallout_CAD/3D_Print/Left Body.stl
130.0 x 167.9 x 98.4

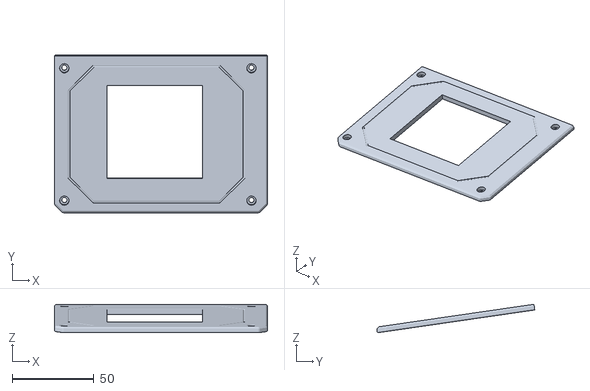
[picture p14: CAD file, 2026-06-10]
Fallout_CAD/3D_Print/Left Bottom Cover.stl
130.0 x 96.2 x 17.3

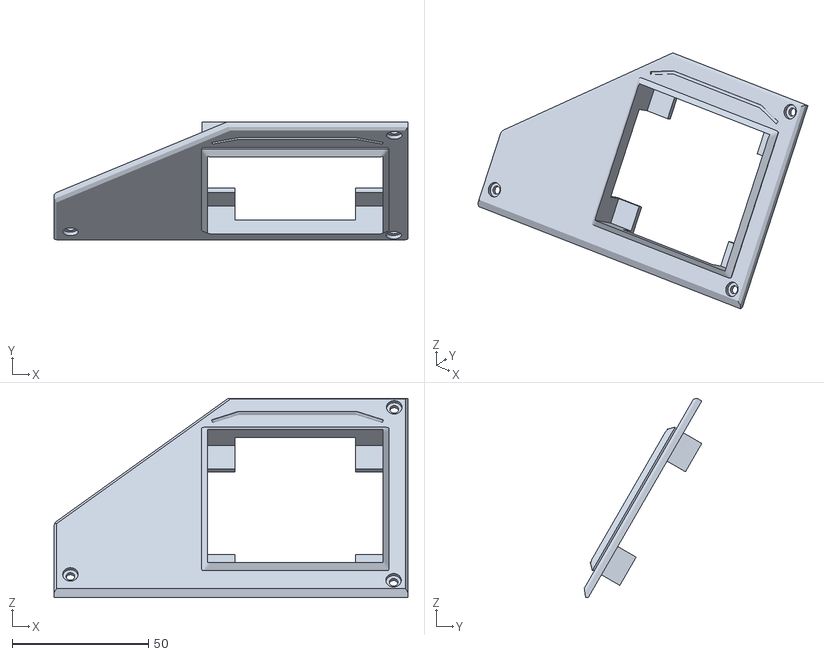
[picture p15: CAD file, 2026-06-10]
Fallout_CAD/3D_Print/Left Top Cover.stl
130.0 x 43.2 x 73.3

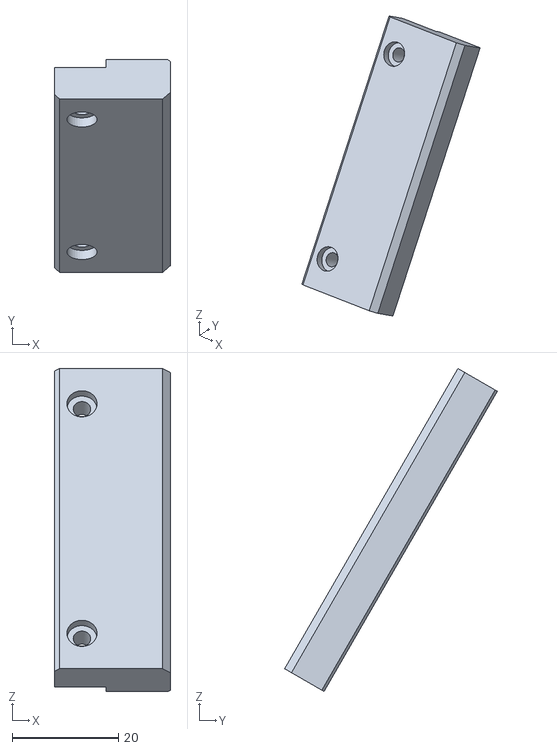
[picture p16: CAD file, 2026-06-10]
Fallout_CAD/3D_Print/Screen Cover Right.stl
21.9 x 40.1 x 60.9

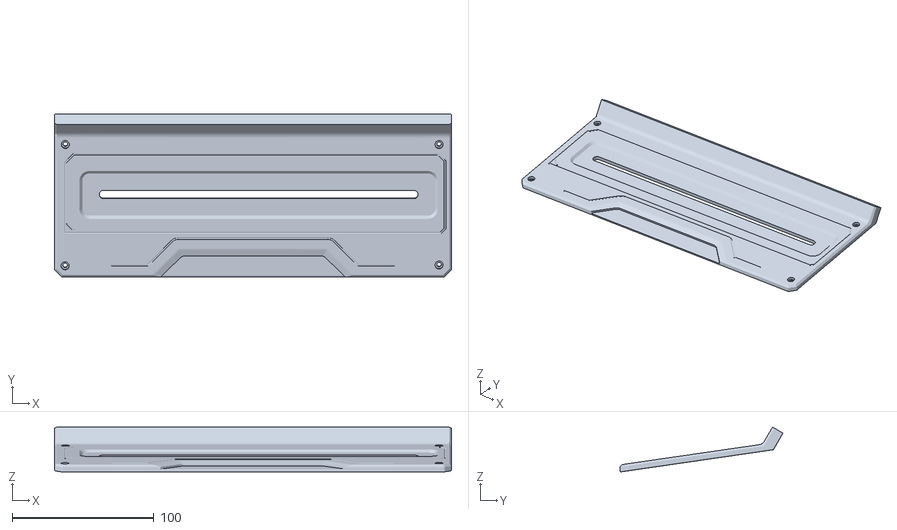
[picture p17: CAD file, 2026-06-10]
Fallout_CAD/3D_Print/Cover.stl
280.0 x 115.0 x 31.6

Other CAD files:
Fallout_CAD/Fallout.f3z

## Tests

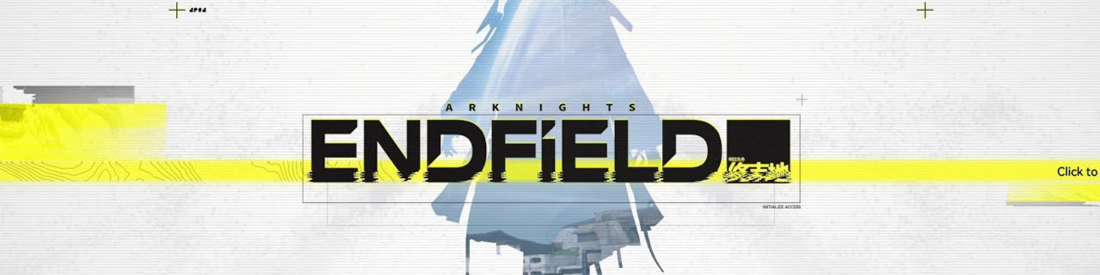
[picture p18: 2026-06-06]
Fallout_UI/Assets/00test.png

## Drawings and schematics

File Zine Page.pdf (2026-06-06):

# //TALOS-01

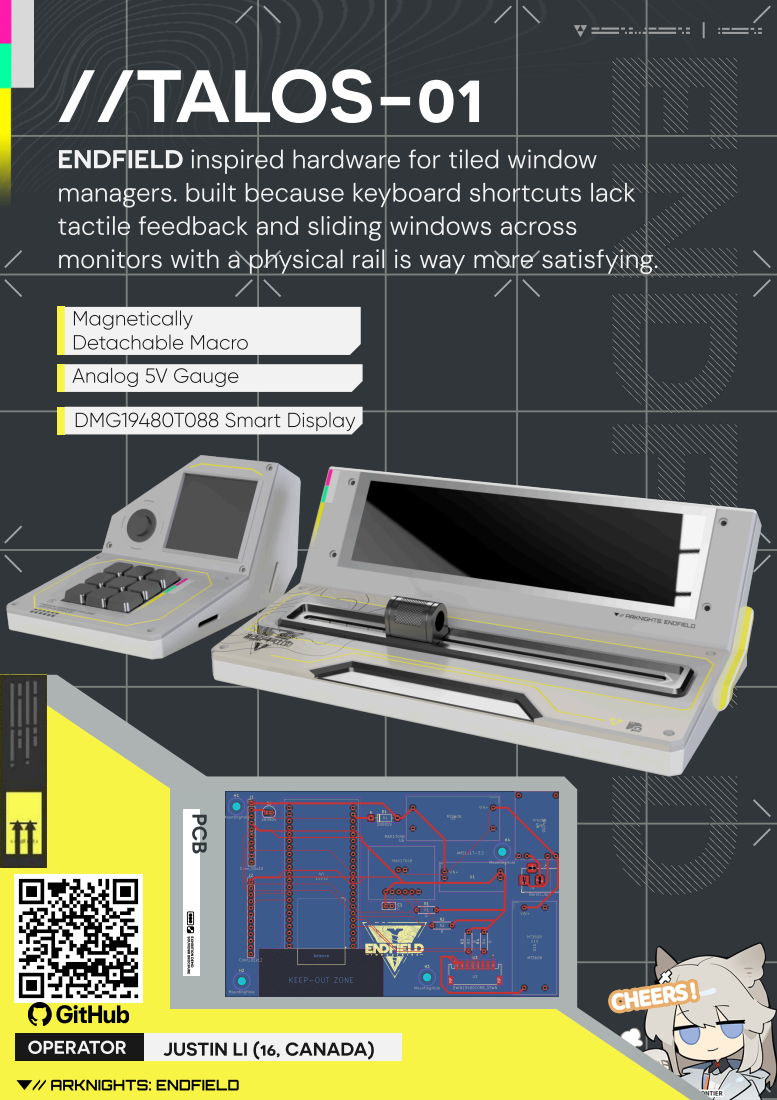
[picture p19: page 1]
tactile feedback; and sliding windows across; monitors with a physical rail; is way more satisfying.; Magnetically Detachable Macro; Analog 5V Gauge; DMG19480T088 Smart Display; OPERATOR; PCB

ENDFIELD inspired hardware for tiled window
managers. built because keyboard shortcuts lack

JUSTIN LI (16, CANADA)

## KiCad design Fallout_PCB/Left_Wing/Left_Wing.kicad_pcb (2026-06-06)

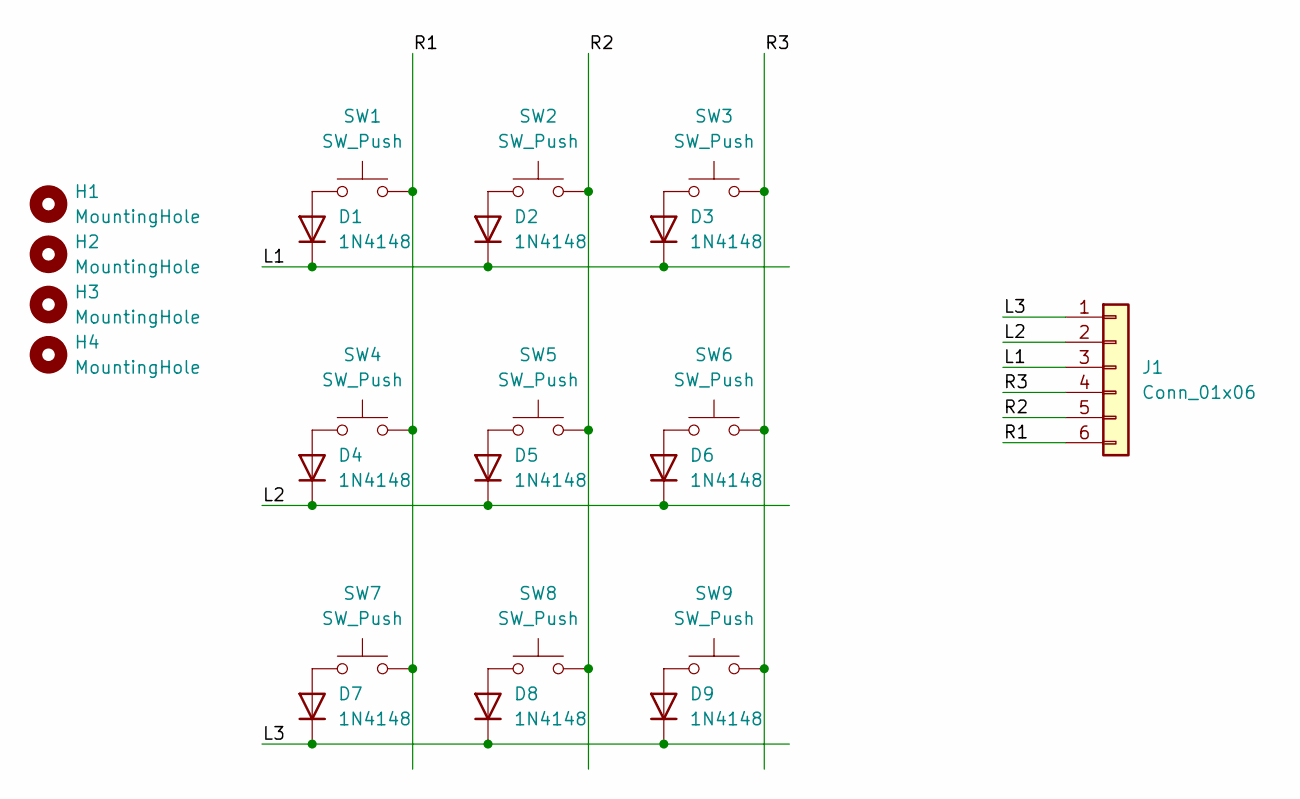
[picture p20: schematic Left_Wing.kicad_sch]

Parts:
D1, D2, D3, D4, D5, D6, D7, D8, D9: 1N4148; Nexperia_CFP3_SOD-123W
H1, H2, H3, H4: MountingHole; MountingHole_2mm
J1: Conn_01x06; PinHeader_1x06_P2.54mm_Vertical
SW1, SW2, SW3, SW4, SW5, SW6, SW7, SW8, SW9: SW_Push; SW_Cherry_MX_1.00u_Plate

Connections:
/L1: D1.1 (K), D2.1 (K), D3.1 (K), J1.3
/L2: D4.1 (K), D5.1 (K), D6.1 (K), J1.2
/L3: D7.1 (K), D8.1 (K), D9.1 (K), J1.1
/R1: J1.6, SW1.2, SW4.2, SW7.2
/R2: J1.5, SW2.2, SW5.2, SW8.2
/R3: J1.4, SW3.2, SW6.2, SW9.2
unnamed: D1.2 (A), SW1.1
unnamed: D2.2 (A), SW2.1
unnamed: D3.2 (A), SW3.1
unnamed: D4.2 (A), SW4.1
unnamed: D5.2 (A), SW5.1
unnamed: D6.2 (A), SW6.1
unnamed: D7.2 (A), SW7.1
unnamed: D8.2 (A), SW8.1
unnamed: D9.2 (A), SW9.1

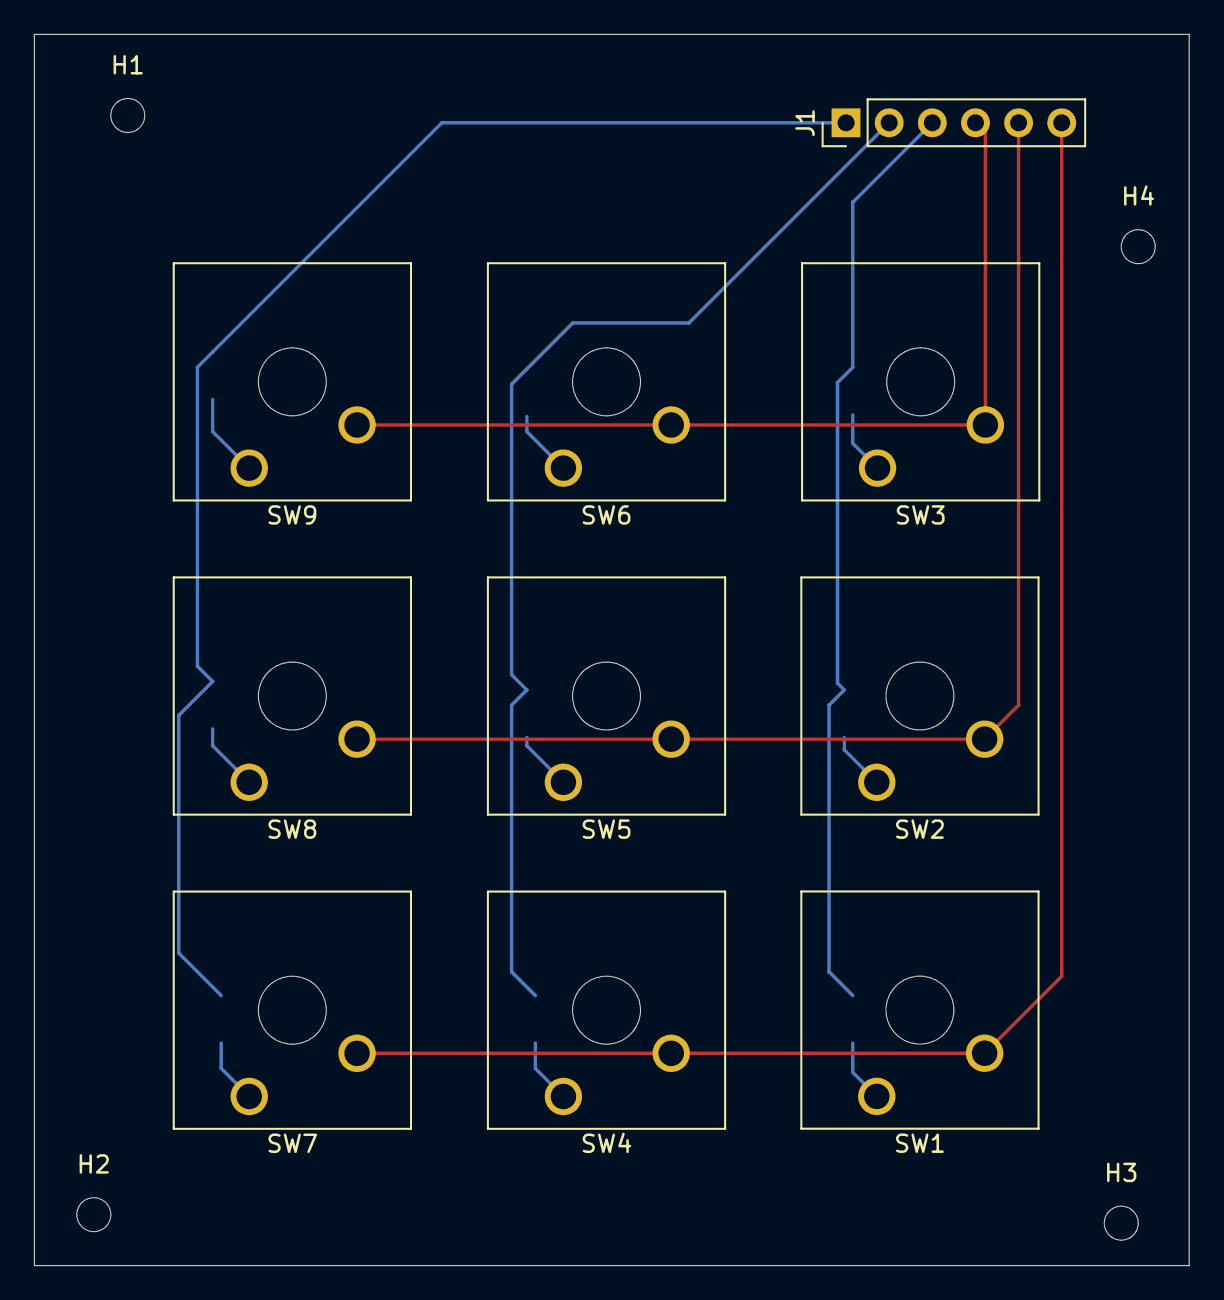
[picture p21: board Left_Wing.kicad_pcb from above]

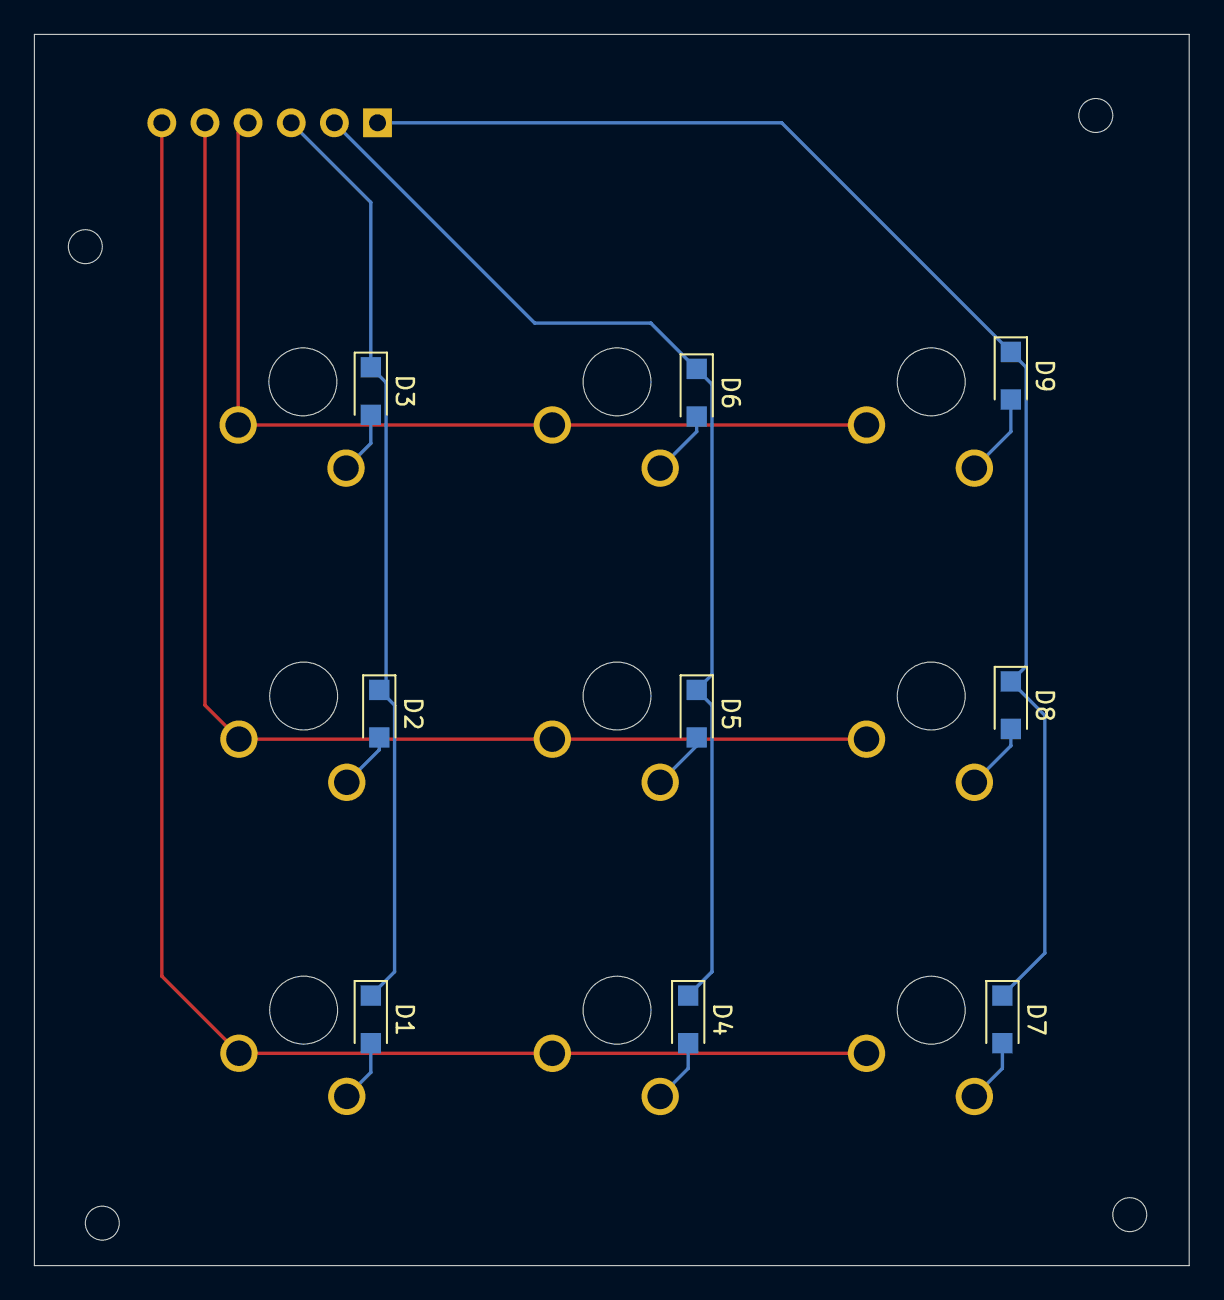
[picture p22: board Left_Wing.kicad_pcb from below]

Board: 2 copper layers, 68.0 x 72.5 mm, 23 parts (9 on the bottom side), 15 nets.

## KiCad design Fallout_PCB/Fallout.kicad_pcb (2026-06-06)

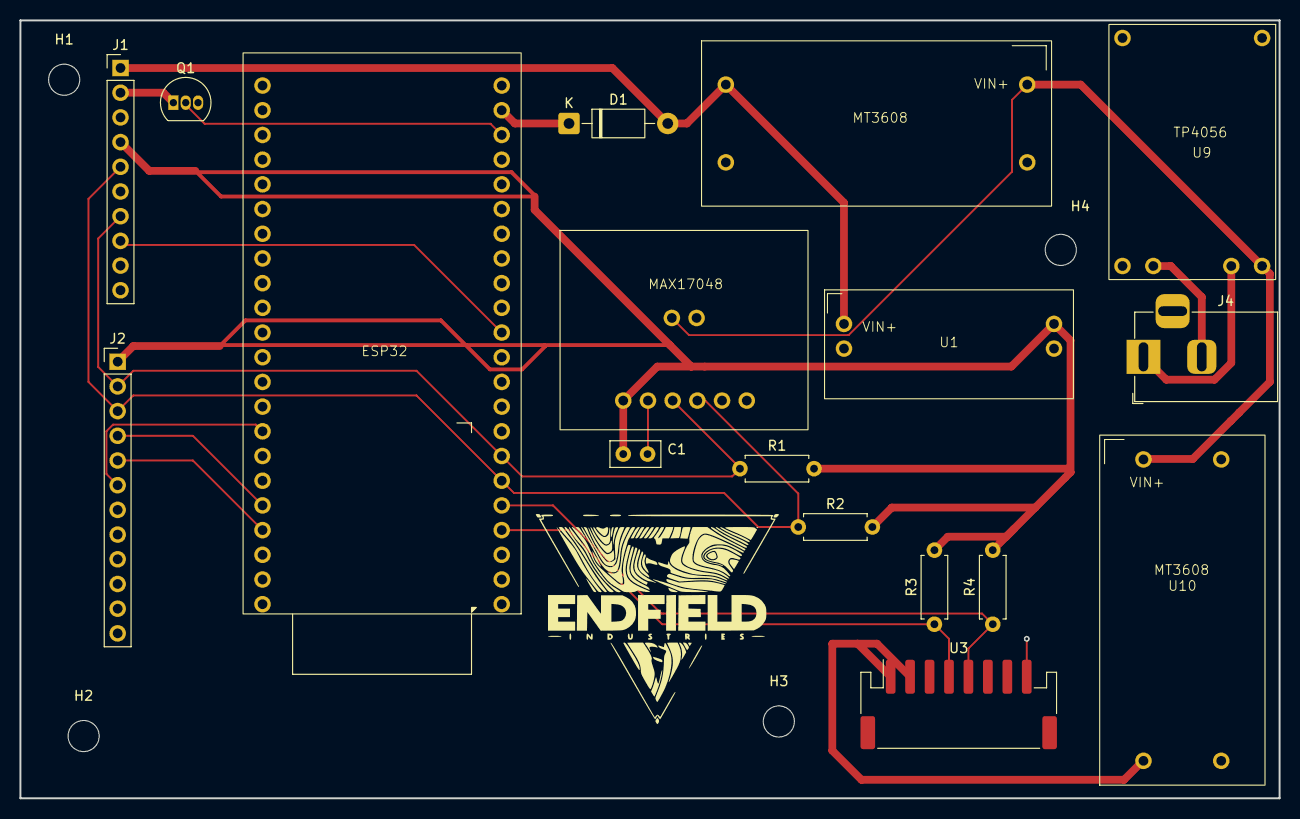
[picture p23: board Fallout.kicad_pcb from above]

Board: 2 copper layers, 129.5 x 80.0 mm, 21 parts (0 on the bottom side), 18 nets.

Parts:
C1: C; C_Disc_D5.0mm_W2.5mm_P2.50mm
D1: 1N5819; D_DO-41_SOD81_P10.16mm_Horizontal
H1, H2, H3, H4: MountingHole; MountingHole_3.2mm_M3
J1: Conn_01x10; PinHeader_1x10_P2.54mm_Vertical
J2: Conn_01x12; PinHeader_1x12_P2.54mm_Vertical
J4: Barrel_Jack; BarrelJack_Horizontal
Q1: 2N3904; TO-92_Inline
R1, R2, R3, R4: R; R_Axial_DIN0207_L6.3mm_D2.5mm_P7.62mm_Horizontal
U1: AMS1117-3.3
U2, U10: MT3608
U3: DWIN19480C088_03WN; JST_PH_S8B-PH-SM4-TB_1x08-1MP_P2.00mm_Horizontal
U4: ESP32-S3-WROOM-1; ESP32_Module
U6: MAX17048
U9: TP4056

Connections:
/5V+: D1.2 (A), J1.1, U1.3 (VI), U2.3 (VOUT+)
/AMS1117_3.3: C1.1, J1.4, J2.1, R1.2, R2.2, R3.2, R4.2, U1.2 (VO), U6.1 (VIN)
/B+: J4.1, U9.5 (B+)
/B-: J4.2, U9.6 (B-)
/DWIN+: U3.1 (VIN), U3.2 (VIN), U10.3 (VOUT+)
/ESP32_INT: J1.8, U4.12 (IO8)
/ESP32_RX: R4.1, U3.5 (TX2), U4.5 (IO5)
/ESP32_SCL: J1.7, J2.2, R1.1, U4.7 (IO7), U6.3 (SCL)
/ESP32_SDA: J1.5, J2.3, R2.1, U4.6 (IO6), U6.4 (SDA)
/ESP32_SS1: J2.4, U4.38 (IO2)
/ESP32_SS2: J2.5, U4.39 (IO1)
/ESP32_SW: J2.6, U4.33 (IO40)
/ESP32_TX: R3.1, U3.4 (RX2), U4.4 (IO4)
/ESP_5V+: D1.1 (K), U4.5Vin (5VIN)
/TP4056+: U2.1 (VIN+), U6.7 (JST+), U9.3 (OUT+), U10.1 (VIN+)
/Voltmeter-: J1.2, Q1.1 (E)
/Voltmeter_Base: Q1.2 (B), U4.22 (IO14)
GND: C1.2, J1.9, J2.12, Q1.3 (C), U1.1 (GND), U2.2 (VIN-), U2.4 (VOUT-), U3.8 (GND), U4.1 (GND), U6.2 (GND), U6.6 (QStart), U6.8 (JST-), U9.4 (OUT-), U10.2 (VIN-), U10.4 (VOUT-)

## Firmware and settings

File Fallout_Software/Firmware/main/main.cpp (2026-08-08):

// main/main.cpp
#include <cstdio>
#include <cstring>  
#include <cmath>
#include "freertos/FreeRTOS.h"
#include "freertos/task.h"
#include "esp_adc/adc_oneshot.h"
#include "esp_log.h"
#include "driver/uart.h"
#include "esp_timer.h" 

// File imports
#include "screen.hpp"
#include "voltmeter.hpp"
#include "input.hpp"
#include "magnetic.hpp"
#include "ble.hpp"

static const char* MAIN_TAG = "FALLOUT_MAIN";

#define SENSOR_A_CHAN ADC_CHANNEL_3 
#define SENSOR_B_CHAN ADC_CHANNEL_4 
#define POLE_PITCH_MM 2.0f

static constexpr float MM_PER_WORKSPACE = 8.0f; 

// EXACT VARIABLE POINTER LAYOUT ADDRESSES
static constexpr uint16_t TIME_TEXT_VP     = 0x3F00;
static constexpr uint16_t DATE_TEXT_VP     = 0x6800;
static constexpr uint16_t WEATHER_TEXT_VP  = 0x6900;
static constexpr uint16_t WEATHER_ICON_VP  = 0x5F00;

// APP ICON POINTER LAYOUT ADDRESS
static constexpr uint16_t APP_ICON_VP      = 0x6B00;

// MPRIS MUSIC POINTER LAYOUT ADDRESSES
static constexpr uint16_t MUSIC_TITLE_VP   = 0x7000;
static constexpr uint16_t MUSIC_ARTIST_VP  = 0x7100;
static constexpr uint16_t MUSIC_STATUS_VP  = 0x7200;

void send_dwin_raw_int(uart_port_t uart_port, uint16_t address, uint16_t value) {
    uint8_t buffer[8];
    buffer[0] = 0x5A; buffer[1] = 0xA5; buffer[2] = 0x05; buffer[3] = 0x82; 
    buffer[4] = static_cast<uint8_t>((address >> 8) & 0xFF);
    buffer[5] = static_cast<uint8_t>(address & 0xFF);
    buffer[6] = static_cast<uint8_t>((value >> 8) & 0xFF);
    buffer[7] = static_cast<uint8_t>(value & 0xFF);
    uart_write_bytes(uart_port, reinterpret_cast<const char*>(buffer), 8);
}

void send_dwin_raw_string(uart_port_t uart_port, uint16_t address, const char* str) {
    uint8_t len = ::strlen(str);
    uint8_t buffer[128];
    buffer[0] = 0x5A;
    buffer[1] = 0xA5;
    buffer[2] = len + 3; 
    buffer[3] = 0x82;
    buffer[4] = static_cast<uint8_t>((address >> 8) & 0xFF);
    buffer[5] = static_cast<uint8_t>(address & 0xFF);
    ::memcpy(&buffer[6], str, len);
    
    if (len % 2 != 0) {
        buffer[6 + len] = 0x00;
        buffer[2]++;
        uart_write_bytes(uart_port, reinterpret_cast<const char*>(buffer), 7 + len);
    } else {
        uart_write_bytes(uart_port, reinterpret_cast<const char*>(buffer), 6 + len);
    }
}

void update_dwin_workspace_apps(uart_port_t uart_port, int workspace_idx, const char* apps_list) {
    if (workspace_idx < 1 || workspace_idx > 10) return;

    uint16_t target_text_vp = 0x2000 + ((workspace_idx - 1) * 0x0100);

    char final_label[16];
    std::snprintf(final_label, sizeof(final_label), "[%d]", workspace_idx);
    send_dwin_raw_string(uart_port, target_text_vp, final_label);
}

extern "C" void app_main(void) {
    vTaskDelay(pdMS_TO_TICKS(500));
    ESP_LOGI(MAIN_TAG, "Starting");

    adc_oneshot_unit_handle_t adc1_handle;
    adc_oneshot_unit_init_cfg_t init_config = {}; 
    init_config.unit_id = ADC_UNIT_1;
    init_config.ulp_mode = ADC_ULP_MODE_DISABLE;
    ESP_ERROR_CHECK(adc_oneshot_new_unit(&init_config, &adc1_handle));

    adc_oneshot_chan_cfg_t adc_cfg = {};
    adc_cfg.atten = ADC_ATTEN_DB_12; 
    adc_cfg.bitwidth = ADC_BITWIDTH_DEFAULT;
    ESP_ERROR_CHECK(adc_oneshot_config_channel(adc1_handle, SENSOR_A_CHAN, &adc_cfg));
    ESP_ERROR_CHECK(adc_oneshot_config_channel(adc1_handle, SENSOR_B_CHAN, &adc_cfg));

    xTaskCreatePinnedToCore(
        fader_tracking_task, 
        "fader_task", 
        4096, 
        (void*)adc1_handle, 
        configMAX_PRIORITIES - 1, 
        nullptr, 
        1
    );

    const uart_port_t dwin_uart = UART_NUM_1;
    uart_config_t uart_config = {};
    uart_config.baud_rate = 115200; 
    uart_config.data_bits = UART_DATA_8_BITS;
    uart_config.parity    = UART_PARITY_DISABLE;
    uart_config.stop_bits = UART_STOP_BITS_1;
    uart_config.flow_ctrl = UART_HW_FLOWCTRL_DISABLE;
    uart_config.source_clk = UART_SCLK_DEFAULT;
    ESP_ERROR_CHECK(uart_param_config(dwin_uart, &uart_config));
    
    ESP_ERROR_CHECK(uart_set_pin(dwin_uart, 4, 5, UART_PIN_NO_CHANGE, UART_PIN_NO_CHANGE));
    ESP_ERROR_CHECK(uart_driver_install(dwin_uart, 1024, 8192, 0, nullptr, 0));
    
    static Screen carousel({.uart_port = dwin_uart, .step_duration_ms = 300});
    
    loadAndSendEmbeddedJpeg(carousel);

    // INLINE STARTUP SLIDE ANIMATION SEQUENCE
    ESP_LOGI(MAIN_TAG, "[BOOT TEST] Initiating workspace sliding sequence...");
    vTaskDelay(pdMS_TO_TICKS(1000)); 
    carousel.scrollToWorkspace(9);
    for (int i = 0; i < 120; ++i) { carousel.update(); vTaskDelay(pdMS_TO_TICKS(10)); }
    vTaskDelay(pdMS_TO_TICKS(1000)); 
    carousel.scrollToWorkspace(1);
    for (int i = 0; i < 240; ++i) { carousel.update(); vTaskDelay(pdMS_TO_TICKS(10)); }
    vTaskDelay(pdMS_TO_TICKS(1000)); 
    carousel.scrollToWorkspace(5);
    for (int i = 0; i < 120; ++i) { carousel.update(); vTaskDelay(pdMS_TO_TICKS(10)); }

    // Set initial icon frame on boot (4 = Kitty)
    send_dwin_raw_int(dwin_uart, APP_ICON_VP, 4);

    static VoltMeter gauge({.gpio_pin = 14, .timer_sel = LEDC_TIMER_0, .channel_sel = LEDC_CHANNEL_0});
    static InputManager inputs({.sda_pin = 6, .scl_pin = 7, .pcf_address = 0x20});
    static BluetoothManager bt_serial("Fallout-Terminal");

    bool last_power = false;
    int32_t last_ticks = 0;
    int last_macro_key = 0;
    uint8_t last_calculated_workspace = 5; 

    // STABILIZED LOCK MECHANISMS
    bool pc_override_lock = false; 
    uint8_t target_pc_workspace = 5;

    while (true) {
        carousel.update();
        inputs.update();

        // 1. POWER BUTTON HANDLER
        bool current_power = inputs.isPowerButtonPressed();
        if (current_power && !last_power) {
            bt_serial.writeString("CMD:POWER_PRESS\n");
        }
        last_power = current_power;

        // 2. PHYSICAL STRIDE SLIDER HANDLER
        int32_t current_ticks = global_ticks;
        float current_mm = (current_ticks * POLE_PITCH_MM) / 4.0f; 

        int target_ws = static_cast<int>(current_mm / MM_PER_WORKSPACE) + 5; 
        if (target_ws < 1)  target_ws = 1;
        if (target_ws > 10) target_ws = 10;

        if (pc_override_lock && target_ws == target_pc_workspace) {
            pc_override_lock = false;
            last_calculated_workspace = static_cast<uint8_t>(target_ws);
            last_ticks = current_ticks; 
            ESP_LOGI(MAIN_TAG, "[LOCK RELEASE] Encoder aligned with PC context at WS %d.", target_ws);
        }

        if (current_ticks != last_ticks) {
            if (!pc_override_lock) {
                char fader_buf[32];
                snprintf(fader_buf, sizeof(fader_buf), "CMD:FADER:%.2f\n", current_mm);
                bt_serial.writeString(fader_buf);
                
                if (static_cast<uint8_t>(target_ws) != last_calculated_workspace) {
                    last_calculated_workspace = static_cast<uint8_t>(target_ws);
                    carousel.scrollToWorkspace(last_calculated_workspace);
                }
            }
            last_ticks = current_ticks;
        }

        // 3. WING MACRO KEY PAD HANDLER
        int current_macro = inputs.getPressedMacroKey();
        if (current_macro != last_macro_key) {
            if (current_macro != 0) {
                char macro_buf[24];
                snprintf(macro_buf, sizeof(macro_buf), "CMD:MACRO:%d\n", current_macro);
                bt_serial.writeString(macro_buf);
            }
            last_macro_key = current_macro;
        }

        // 4. INBOUND WIRELESS DATA ROUTER
        if (bt_serial.available()) {
            std::string msg = bt_serial.readStringUntil('\n');
            
            if (msg.rfind("STATS:", 0) == 0) {
                float cpu = 0.0f, ram = 0.0f;
                if (std::sscanf(msg.c_str(), "STATS:CPU:%f:RAM:%f", &cpu, &ram) == 2) {
                    float target_voltage = (cpu / 100.0f) * 5.0f;
                    gauge.setVoltage(target_voltage);
                }
            }
            else if (msg.rfind("TIME:", 0) == 0) {
                int hour = 0, minute = 0;
                if (std::sscanf(msg.c_str(), "TIME:%d:%d", &hour, &minute) == 2) {
                    char time_label[16];
                    std::snprintf(time_label, sizeof(time_label), "%02d:%02d", hour, minute);
                    
                    ESP_LOGI(MAIN_TAG, "[BLE INBOUND] Received Time Sync: %s", time_label);
                    send_dwin_raw_string(dwin_uart, TIME_TEXT_VP, time_label);
                }
            }
            else if (msg.rfind("DATE:", 0) == 0) {
                int year = 0, month = 0, day = 0;
                if (std::sscanf(msg.c_str(), "DATE:%d:%d:%d", &year, &month, &day) == 3) {
                    char date_label[24];
                    std::snprintf(date_label, sizeof(date_label), "%04d-%02d-%02d", year, month, day);
                    
                    ESP_LOGI(MAIN_TAG, "[BLE INBOUND] Received Date Sync: %s", date_label);
                    send_dwin_raw_string(dwin_uart, DATE_TEXT_VP, date_label);
                }
            }
            else if (msg.rfind("WEATHER:", 0) == 0) {
                char weather_layout[64] = {0};
                if (std::sscanf(msg.c_str(), "WEATHER:%63[^\n]", weather_layout) == 1) {
                    ESP_LOGI(MAIN_TAG, "[BLE INBOUND] Received Temperature: %s", weather_layout);
                    send_dwin_raw_string(dwin_uart, WEATHER_TEXT_VP, weather_layout);
                }
            }
            else if (msg.rfind("W_ICON:", 0) == 0) {
                int parsed_icon = 0;
                if (std::sscanf(msg.c_str(), "W_ICON:%d", &parsed_icon) == 1) {
                    ESP_LOGI(MAIN_TAG, "[BLE INBOUND] Received Weather Icon Index: %d", parsed_icon);
                    send_dwin_raw_int(dwin_uart, WEATHER_ICON_VP, static_cast<uint16_t>(parsed_icon));
                }
            }
            else if (msg.rfind("APP_ICON:", 0) == 0) {
                int parsed_icon = 0;
                if (std::sscanf(msg.c_str(), "APP_ICON:%d", &parsed_icon) == 1) {
                    ESP_LOGI(MAIN_TAG, "[BLE INBOUND] Received App Icon Index: %d", parsed_icon);
                    carousel.setAppIcon(static_cast<uint16_t>(parsed_icon));
                }
            }
            else if (msg.rfind("MUSIC:", 0) == 0) {
                char status[16] = {0};
                char artist[64] = {0};
                char title[64] = {0};

                if (std::sscanf(msg.c_str(), "MUSIC:%15[^:]:%63[^:]:%63[^\r\n]", status, artist, title) == 3) {
                    ESP_LOGI(MAIN_TAG, "[BLE INBOUND MUSIC] [%s] %s - %s", status, artist, title);

                    send_dwin_raw_string(dwin_uart, MUSIC_TITLE_VP, title);
                    send_dwin_raw_string(dwin_uart, MUSIC_ARTIST_VP, artist);
                    send_dwin_raw_string(dwin_uart, MUSIC_STATUS_VP, status);
                }
            }
            else if (msg.rfind("WS_MAP:", 0) == 0) {
                int target_workspace = 1;
                char apps_layout[256] = {0}; 
                
                int matched = std::sscanf(msg.c_str(), "WS_MAP:%d:%255[^:\n]", &target_workspace, apps_layout);
                if (matched >= 1) {
                    update_dwin_workspace_apps(dwin_uart, target_workspace, "");
                    
                    if (static_cast<uint8_t>(target_workspace) != target_pc_workspace) {
                        target_pc_workspace = static_cast<uint8_t>(target_workspace);
                        pc_override_lock = true; 
                        
                        carousel.scrollToWorkspace(target_pc_workspace);
                    }
                }
            }
        }

        vTaskDelay(pdMS_TO_TICKS(20)); 
    }
}

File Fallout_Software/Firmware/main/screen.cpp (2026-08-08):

// main/screen.cpp
#include <cstdint>
#include <cmath>
#include <cstring>
#include <cstdio>
#include <algorithm>
#include "screen.hpp"
#include "driver/uart.h"
#include "esp_timer.h"
#include "esp_log.h"
#include "freertos/FreeRTOS.h"
#include "freertos/task.h"

static const char* TAG = "CAROUSEL_ENGINE";

extern "C" {
    extern const uint8_t image_start[] asm("_binary_1_jpg_start");
    extern const uint8_t image_end[]   asm("_binary_1_jpg_end");
}

static constexpr uint16_t ADDR_INCREMENT = 0x0100;
static constexpr uint16_t ICON_SP_BASE   = 0x3000;
static constexpr uint16_t ICON_VP_BASE   = 0x4000;
static constexpr uint16_t TEXT_SP_BASE   = 0x5000;
static constexpr uint16_t TEXT_VP_BASE   = 0x2000; 

// APP ICON POINTER LAYOUT ADDRESSES
static constexpr uint16_t APP_ICON_SP    = 0x6A00;
static constexpr uint16_t APP_ICON_VP    = 0x6B00;

// ============================================================================
// APP ICON OFFSET CONFIGURATION
// ============================================================================
static constexpr int16_t APP_ICON_OFFSET_X = 100; 
static constexpr int16_t APP_ICON_OFFSET_Y = 150; 

static constexpr uint16_t COLOR_YELLOW   = 0xFFE0; 
static constexpr uint16_t COLOR_BLACK    = 0x0000; 

static constexpr uint16_t SIZE_PACKED_REST   = 0x2424; 
static constexpr uint16_t SIZE_PACKED_ACTIVE = 0x4848; 

Screen::Screen(const Config& config)
    : cfg_(config),
      state_(State::IDLE),
      current_focus_idx_(4),       
      target_step_idx_(4),
      ultimate_target_idx_(4),
      stride_balance_delta_(0),    
      current_global_pos_(4),      
      queued_workspace_(4),        
      is_floor_move_(false),       
      g_local_slide_x(0.0f),
      shifting_right_(false),
      starting_x_(10.0f),
      slot_spacing_(90.0f),    
      transition_start_time_us_(0),
      last_log_time_ms_(0),
      update_ticker_(0),
      pending_app_icon_id_(4),
      last_sent_app_icon_id_(0xFFFF),
      app_icon_needs_update_(true) {
    
    for (int i = 0; i < 10; ++i) {
        uniform_slots_x_[i] = static_cast<uint16_t>(starting_x_ + (i * slot_spacing_));
    }

    for (int i = 0; i < 10; ++i) {
        last_sent_frames_[i] = 0xFFFF;
        text_values_[i] = i+1; 
    }

    for (int i = 0; i < 10; ++i) {
        uint16_t init_frame = (i == current_focus_idx_) ? 7 : 0;
        last_sent_frames_[i] = init_frame;
        sendDwinWriteSingle(ICON_VP_BASE + (i * ADDR_INCREMENT), init_frame);
        sendDwinWriteSingle(TEXT_SP_BASE + (i * ADDR_INCREMENT) + 3, COLOR_BLACK);

        uint16_t init_size = (i == current_focus_idx_) ? 0x4848 : 0x2424;
        sendDwinWriteSingle(TEXT_SP_BASE + (i * ADDR_INCREMENT) + 0x0A, init_size);

        char str_buf[8];
        snprintf(str_buf, sizeof(str_buf), "[%d]", text_values_[i]);
        sendDwinString(TEXT_VP_BASE + (i * ADDR_INCREMENT), str_buf);
    }

    updateHardwarePositions(0.0f);
    ESP_LOGI(TAG, "Dynamic Relay Multi-Stride Engine loaded. Anchored on Index [%d]", current_focus_idx_);
}

void Screen::setAppIcon(uint16_t icon_id) {
    if (pending_app_icon_id_ != icon_id) {
        pending_app_icon_id_ = icon_id;
        app_icon_needs_update_ = true;
    }
}

void Screen::scrollToWorkspace(uint8_t target_idx) {
    if (target_idx > 0) {
        target_idx -= 1; 
    } else {
        target_idx = 0; 
    }

    if (target_idx > 9) target_idx = 9; 
    ultimate_target_idx_ = target_idx;
    
    stride_balance_delta_ += static_cast<int8_t>(target_idx) - static_cast<int8_t>(queued_workspace_); 
    queued_workspace_ = target_idx;
}

void Screen::swipeLeft() {
    if (state_ != State::IDLE) return;

    shifting_right_ = false;
    target_step_idx_ = current_focus_idx_ + 1; 
    
    transition_start_time_us_ = esp_timer_get_time();
    state_ = State::MOVING;
    ESP_LOGI(TAG, "[STRIDE LEFT] Moving: Element [%u] -> Slot 4 Spotlight Pass", (unsigned int)target_step_idx_);
}

void Screen::swipeRight() {
    if (state_ != State::IDLE) return;

    shifting_right_ = true;
    target_step_idx_ = current_focus_idx_ - 1; 
    
    transition_start_time_us_ = esp_timer_get_time();
    state_ = State::MOVING;
    ESP_LOGI(TAG, "[STRIDE RIGHT] Moving: Element [%u] -> Slot 4 Spotlight Pass", (unsigned int)target_step_idx_);
}

void Screen::updateHardwarePositions(float ease_progress) {
    update_ticker_++;
    bool allow_property_update = (state_ == State::IDLE) || (update_ticker_ % 3 == 0);

    float current_focus_x = 0.0f, current_focus_y = 0.0f;
    float target_focus_x = 0.0f, target_focus_y = 0.0f;

    for (uint16_t i = 0; i < 10; ++i) {
        float slot_x = static_cast<float>(uniform_slots_x_[i]);
        float split_offset = 0.0f;

        if (state_ == State::MOVING) {
            if (!shifting_right_) { 
                if (i < current_focus_idx_) {
                    split_offset = -CUSHION_PADDING;
                } else if (i > target_step_idx_) {
                    split_offset = CUSHION_PADDING;
                } else if (i == current_focus_idx_) {
                    split_offset = -CUSHION_PADDING * ease_progress; 
                } else if (i == target_step_idx_) {
                    split_offset = CUSHION_PADDING * (1.0f - ease_progress); 
                }
            } else { 
                if (i < target_step_idx_) {
                    split_offset = -CUSHION_PADDING;
                } else if (i > current_focus_idx_) {
                    split_offset = CUSHION_PADDING;
                } else if (i == target_step_idx_) {
                    split_offset = -CUSHION_PADDING * (1.0f - ease_progress); 
                } else if (i == current_focus_idx_) {
                    split_offset = CUSHION_PADDING * ease_progress;         
                }
            }
        } else {
            if (i < current_focus_idx_) {
                split_offset = -CUSHION_PADDING;
            } else if (i > current_focus_idx_) {
                split_offset = CUSHION_PADDING;
            } else {
                split_offset = 0.0f;
            }
        }

        float active_slide_x = g_local_slide_x;
        if (is_floor_move_) {
            active_slide_x = 0.0f;
        }

        uint16_t dynamic_x = static_cast<uint16_t>(slot_x + split_offset + active_slide_x);

        float icon_y_calculated = static_cast<float>(FORCED_Y_BASELINE);
        float text_y_calculated = static_cast<float>(FORCED_Y_BASELINE + REST_TEXT_Y_OFFSET);
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

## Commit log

2026-06-06 Fixed Firmware Nested Repo
    [input.cpp, magnetic.cpp, main.cpp]
2026-06-06 Added BOM
    [BOM.xlsx]
2026-06-06 Fixed File Format, and using Git LFS
    [Fallout.3mf, Fallout.f3z]
2026-06-06 Gerbers, Markdown, and Go files
    [BOM.csv, BOM.xlsx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]
2026-06-07 Cleaned up Repository
    [Fallout.baka.kicad_pcb]
2026-06-10 Updated BOM with English version
    [BOM.csv, BOM.xlsx]
2026-06-10 Updated BOM with English Ver.
    [BOM.csv, BOM.xlsx]
2026-06-10 Changed BOM format to UTF-8 CSV
    [BOM.csv]
2026-08-07 awmc😍
